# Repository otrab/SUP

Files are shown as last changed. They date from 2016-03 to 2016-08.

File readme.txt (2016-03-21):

Readme

Current on HDMI 5v line
http://forum.xda-developers.com/showthread.php?t=2384480

HDMI specification
https://en.wikipedia.org/wiki/HDMI
http://www.hdmi.org/installers/insidehdmicable.aspx

Great ideas
http://forum.arduino.cc/index.php?topic=119879.0
http://articulo.mercadolibre.cl/MLC-432821282-switch-hdmi-hasta-3-dispositivos-1080p-_JM ($4.800)
http://www.aliexpress.com/item/1pc-Switcher-Splitter-Cable-For-HDTV-3-IN-1-OUT-1080P-Hub-V1-4B-HDMI-Switch/32291909706.html

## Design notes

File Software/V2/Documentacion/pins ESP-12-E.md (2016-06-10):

# Pines ESP-12-E

Pin fisico | Puerto | Pin Arduino | Funciones internas
-----------|--------|-------------|-------------------
1          | RST    |             |
2          | ADC    | A0          | TOUT
3          | EN     |             |
4          | GPIO16 | 0           | WAKE
5          | GPIO14 | 5           | HSPICLK
6          | GPIO12 | 6           | HSPIQ
7          | GPIO13 | 7           | HSPID/CTS0/RXD2
8          | VDD    |             |
9          | GND    |             |
10         | GPIO15 | 8           | HSPICS/RTS0/TXD2
11         | GPIO2  | 4           | TXD1
12         | GPIO0  | 3           | SPICS2
13         | GPIO4  | 2           |
14         | GPIO5  | 1           |
15         | GPIO3  | 9           | RXD0
16         | GPIO1  | 10          | SPICS1/TXD0
17         | CS0    |             | SPI_INT/SD_D1
18         | MISO   |             | SPI_MISO/SD_D0
19         | GPIO9  |             | SD_D2
20         | GPIO10 |             | SPI_CS/SD_D3
21         | MOSI   |             | SPI_MOSI/SD_CMD
22         | SCLK   |             | SPI_CLK/SD_CLK

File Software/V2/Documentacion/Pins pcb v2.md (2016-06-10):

# Documentacion firmware V2
## Pines ATmega PCB V2

Pin TQFP | Puerto | Pin Arduino | Funciones internas | PCB            | Estados
---------|--------|-------------|--------------------|----------------|--------
1        | PD3    | 3           | PCINT19/OC2B/INT1  | EXP            | X
2        | PD4    | 4           | PCINT20/XCK/T0     | EXP            | X
9        | PD5    | 5           | PCINT21/OC0B/T1    | EXP            | X
10       | PD6    | 6           | PCINT22/OC0A/AIN0  | ESP_GPIO13_3V3 | 0 1 Z
11       | PD7    | 7           | PCINT23/AIN1       | RFID_OC_NRST   | 0 Z
12       | PB0    | 8           | PCINT0/CLKO/ICP1   | RFID_SS_3V3    | 0 1
13       | PB1    | 9           | PCINT1/OC1A        | LED            | 0 1
14       | PB2    | 10          | PCINT2/SS/OC1B     | EXP            | X
15       | PB3    | 11          | PCINT3/OC2A/MOSI   | RFID_MOSI_3V3  | 0 1
16       | PB4    | 12          | PCINT4/MISO        | RFID_MISO_3V3  | Z
17       | PB5    | 13          | SCK/PCINT5         | RFID_SCK_3V3   | 0 1
19       | ADC6   | -           |                    | EXP            |
22       | ADC7   | -           |                    | BOTON          | Z
23       | PC0    | A0          | ADC0/PCINT8        | BUZZER         | 0 1
24       | PC1    | A1          | ADC1/PCINT9        | RELE           | 0 1
25       | PC2    | A2          | ADC2/PCINT10       | HDMI_A_5V      | Z
26       | PC3    | A3          | ADC3/PCINT11       | HDMI_B_5V      | Z
27       | PC4    | A4          | ADC4/SDA/PCINT12   | SDA            | 0 1 Z
28       | PC5    | A5          | ADC5/SCL/PCINT13   | SCL            | 0 1 Z
29       | PC6    | RESET       | RESET/PCINT14      | RST_ATM_3V3    | Z
30       | PD0    | 0           | RXD/PCINT16        | ESP_TX_3V3     | Z
31       | PD1    | 1           | TXD/PCINT17        | ESP_RX_3V3     | 0 1
32       | PD2    | 2           | INT0/PCINT18       | EXP            | X

## Pines ESP PCB V2

Pin fisico | Puerto | Pin Arduino | Funciones internas | PCB            | Estados
-----------|--------|-------------|--------------------|----------------|--------
1          | RST    |             | RESET              | ESP_OC_NRST    |
2          | ADC    | A0          | TOUT               |                |
4          | GPIO16 | 16          | WAKE               |                | X
5          | GPIO14 | 14          | HSPICLK            | BOTON          | Z
6          | GPIO12 | 12          | HSPIQ              |                | X
7          | GPIO13 | 13          | HSPID/CTS0/RXD2    | ESP_GPIO13_3V3 | 0 1 Z
10         | GPIO15 | 15          | HSPICS/RTS0/TXD2   |                | Z
11         | GPIO2  | 2           | TXD1               |                | Z
12         | GPIO0  | 0           | SPICS2             | ESP_OC_NPROG   | Z
13         | GPIO4  | 4           |                    | RST_ATM_3V3    | 0 1
14         | GPIO5  | 5           |                    |                | X
15         | GPIO3  | 3           | RXD0               | ESP_RX_3V3     | Z
16         | GPIO1  | 1           | SPICS1/TXD0        | ESP_TX_3V3     | 0 1
17         | CS0    |             | SPI_INT/SD_D1      |                |
18         | MISO   |             | SPI_MISO/SD_D0     |                |
19         | GPIO9  |             | SD_D2              |                |
20         | GPIO10 |             | SPI_CS/SD_D3       |                |
21         | MOSI   |             | SPI_MOSI/SD_CMD    |                |
22         | SCLK   |             | SPI_CLK/SD_CLK     |                |

###Notas
Los estados permitidos de los pines se especifican para los pines configurables, ademas:
- Salida:
    - 0 = 0V
    - 1 = 3.3V 5V
- Entrada = Z (Alta impedancia)
- X = 0 1 Z (No importa pero deberian quedar en Z con pullup interno si no se usan)

El nodo ESP_GPIO13_3V3 conecta PD6 del ATmega con GPIO13 en el ESP, es importante que no queden ambos configurados como salida al mismo tiempo, siempre tiene que haber uno en Z.

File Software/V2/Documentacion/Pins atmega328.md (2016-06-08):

# Pines ATmega328 TQFP

Pin TQFP | Puerto | Pin Arduino | Funciones
---------|--------|-------------|-------------------
1        | PD3    | 3           | PCINT19/OC2B/INT1
2        | PD4    | 4           | PCINT20/XCK/T0
3        | GND    |             |
4        | VCC    |             |
5        | GND    |             |
6        | VCC    |             |
7        | PB6    | -           | PCINT6/XTAL1/TOSC1
8        | PB7    | -           | PCINT7/XTAL2/TOSC2
9        | PD5    | 5           | PCINT21/OC0B/T1
10       | PD6    | 6           | PCINT22/OC0A/AIN0
11       | PD7    | 7           | PCINT23/AIN1
12       | PB0    | 8           | PCINT0/CLKO/ICP1
13       | PB1    | 9           | PCINT1/OC1A
14       | PB2    | 10          | PCINT2/SS/OC1B
15       | PB3    | 11          | PCINT3/OC2A/MOSI
16       | PB4    | 12          | PCINT4/MISO
17       | PB5    | 13          | SCK/PCINT5
18       | AVCC   |             |
19       | ADC6   | -           |
20       | AREF   | AREF        |
21       | GND    |             |
22       | ADC7   | -           |
23       | PC0    | A0          | ADC0/PCINT8
24       | PC1    | A1          | ADC1/PCINT9
25       | PC2    | A2          | ADC2/PCINT10
26       | PC3    | A3          | ADC3/PCINT11
27       | PC4    | A4          | ADC4/SDA/PCINT12
28       | PC5    | A5          | ADC5/SCL/PCINT13
29       | PC6    | RESET       | RESET/PCINT14
30       | PD0    | 0           | RXD/PCINT16
31       | PD1    | 1           | TXD/PCINT17
32       | PD2    | 2           | INT0/PCINT18

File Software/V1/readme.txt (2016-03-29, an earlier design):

Opté por partir utilizando Arduíno para programar el ESP8266.

IDE preparado:

https://github.com/esp8266/Arduino/

	Install Arduino 1.6.8 from the Arduino website.
	Start Arduino and open Preferences window.
	Enter http://arduino.esp8266.com/stable/package_esp8266com_index.json into Additional Board Manager URLs field. You can add multiple URLs, separating them with commas.
	Open Boards Manager from Tools > Board menu and install esp8266 platform (and don't forget to select your ESP8266 board from Tools > Board menu after installation).

Referencias: 

https://github.com/esp8266/Arduino/blob/master/doc/reference.md

RTC wiki:

http://www.seeedstudio.com/wiki/index.php?title=Twig_-_RTC

https://git-scm.com/book/es/v1/Fundamentos-de-Git-Guardando-cambios-en-el-repositorio
Un firmware por cada componente para probarlos en el atmega.
Un firmware para el atmega que integra todos los componentes.
Un firmware para el esp8266 que incluye un servidor web local y envia la configuración por serial al atmega.

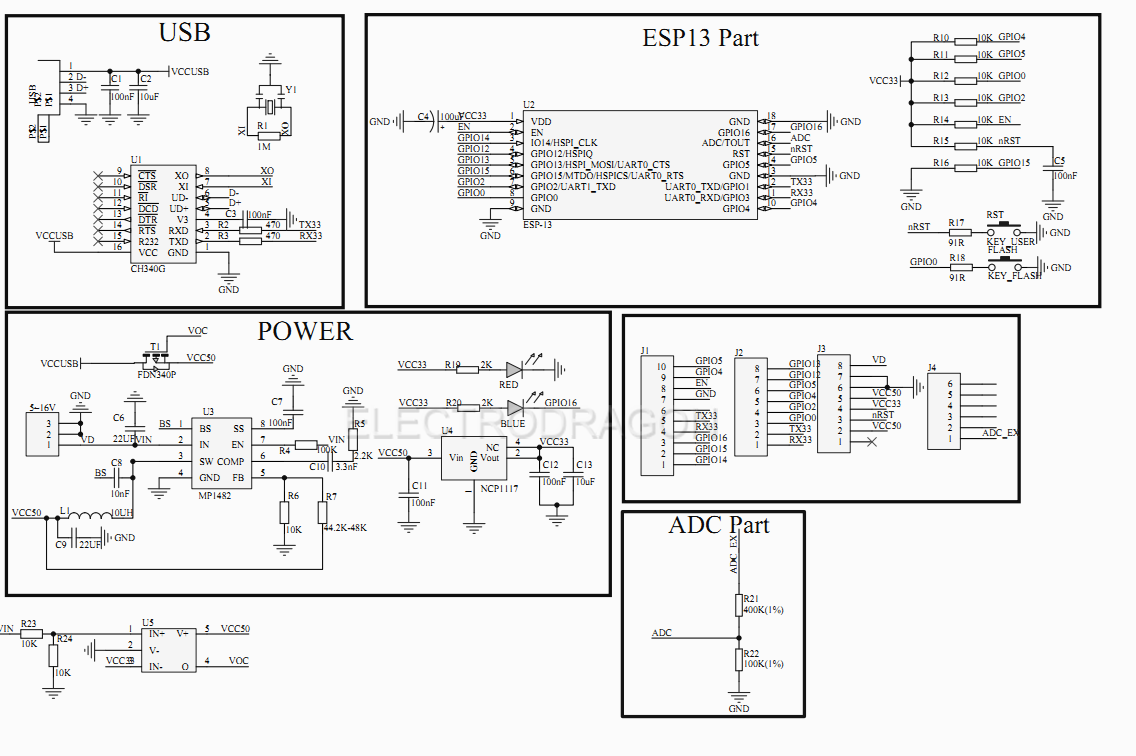
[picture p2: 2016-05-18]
Hardware/Material/ESP13-arduino_schematic.png

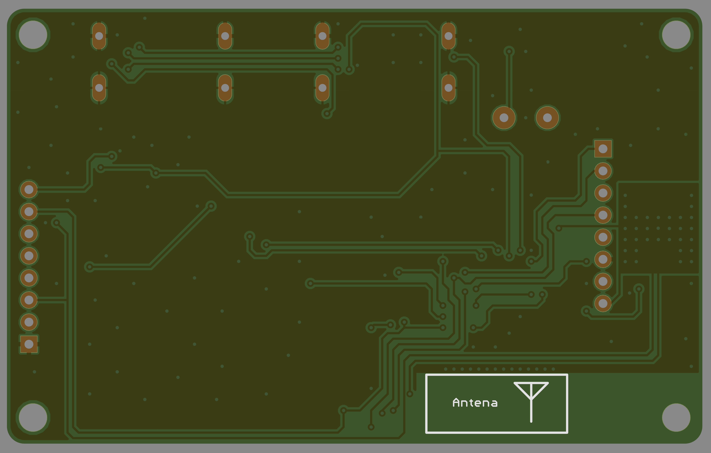
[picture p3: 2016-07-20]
Hardware/pcb v3/bottom.png

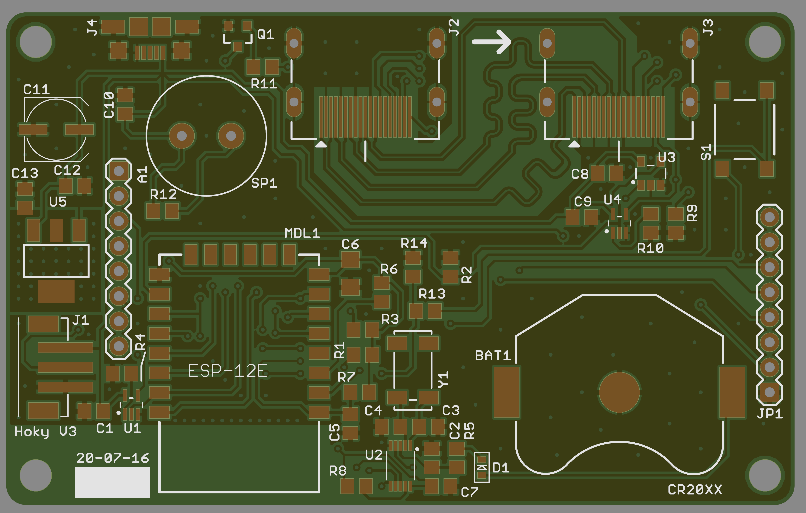
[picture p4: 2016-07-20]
Hardware/pcb v3/top.png

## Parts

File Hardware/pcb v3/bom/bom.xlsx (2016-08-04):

Qty | Value | Device | Package | Parts | Fabricante | Codigo fabricante | Codigo digikey | Description
1 | RFID-RC522 | RFID-RC522 | RFID-RC522 | A1
1 | BAT-HLD-001 | LINX-BAT-HLD-00120SMD | BATTCON_20MM | BAT1 | Linx Technologies Inc. | BAT-HLD-001 | BAT-HLD-001-ND | Battery Holders
6 | 100nF | C-USC0805 | C0805 | C1, C5, C7, C8, C9, C10 |  |  | 478-1395-1-ND | CAPACITOR, American symbol
1 | 100uF | CPOL-US | UD-6,3X5,8_NICHICON_LPADS | C11 |  |  | 565-2075-1-ND
2 | 10uF | C-USC0805 | C0805 | C12, C13 |  |  | 490-10516-1-ND | CAPACITOR, American symbol
1 | 100pF | C-USC0805 | C0805 | C2 |  |  | 399-1122-1-ND | CAPACITOR, American symbol
2 | 18pF | C-USC0805 | C0805 | C3, C4 |  |  | 709-1171-1-ND | CAPACITOR, American symbol
1 | 100uF | C-USC1206 | C1206 | C6 |  |  | 587-3395-1-ND | CAPACITOR, American symbol
1 | DB2S311 | DIODESOD-523 | SOD-523 | D1 | Panasonic Electronic Components | DB2S31100L | DB2S31100LCT-ND | Diode
1 | JST-3 | JST-3 | B3B-PH-SM4-TB | J1 | JST Sales America Inc. | B3B-PH-SM4-TB(LF)(SN) | 455-1735-1-ND
2 | HDMI | HDMI | 471511071 | J2, J3 | Molex, LLC | 471511071 | WM7083CT-ND
1 | 1981584-1 | 1981584-1 | 1981584-1 | J4 | TE Connectivity AMP Connectors | 1981584-1 | A97799CT-ND | Receptacle, micro-USB, type A/B
1 |  | M081X08 | 1X08 | JP1 |  |  | S1011EC-40-ND | Header 8
1 |  | ESP8266-12EESP8266-ESP12E | ESP8266-ESP12E | MDL1 |  |  |  | ESP8266-12E with additional I/O and GPIO04/05 corrected
1 | PMBT3904 | PMBT3904 | SOT-23-3 | Q1 |  |  | 568-1741-1-ND | PMBT3904
13 | 10k | R-US_R0805 | R0805 | R1, R2, R3, R4, R6, R7, R8, R9, R10, R13, R14, R15, R16 |  |  | RMCF0805JT10K0CT-ND | RESISTOR, American symbol
3 | 1k | R-US_R0805 | R0805 | R5, R11, R12 |  |  | RMCF0805JT1K00CT-ND | RESISTOR, American symbol
1 | PULSADOR-SPST-SMD-1-3-4 | PULSADOR-SPST-SMD-1-3-4 | PTS645SM43SMTR92 | S1 | C&K Components | PTS645SM43SMTR92 LFS | CKN9112CT-ND
1 | SPEAKER/PS12 | SPEAKER/PS12 | PS12 | SP1 | TDK Corporation | PS1240P02BT | 445-2525-1-ND
2 | 74HCT1G125GW | 74HCT1G125GW | SOT65P210X110-5N | U1, U4 | NXP Semiconductors | 74HCT1G125GW,125 | 568-4582-1-ND | Bus buffer/line driver
1 | MCP79510 | MCP79510 | MSOP10 | U2 | Microchip Technology | MCP79510-I/MS | MCP79510-I/MS-ND
1 | MC74VHC1GT66 | MC74VHC1GT66 | TSOP-5 | U3 | ON Semiconductor | M74VHC1GT66DTT1G | M74VHC1GT66DTT1GOSCT-ND
1 | NCP1117LPST33T3G | V_REG_LM1117SOT223 | SOT223 | U5 | ON Semiconductor | NCP1117LPST33T3G | NCP1117LPST33T3GOSCT-ND | Voltage Regulator LM1117
1 | CRYSTAL.ABS25 | CRYSTAL.ABS25 | ABS25 | Y1 | Abracon LLC | ABS25-32.768KHZ-T | 535-9166-2-ND
 | Precios digikey:
 | v3 x35 | $11.97 | 15x4
 | v2 x35 | $22.26
 |  | 46.22898216%
 | v3 x100 | $10.09
 | v2 x100 | $19.52
 |  | 48.28483607%
 | v3 x1000 | $7.13

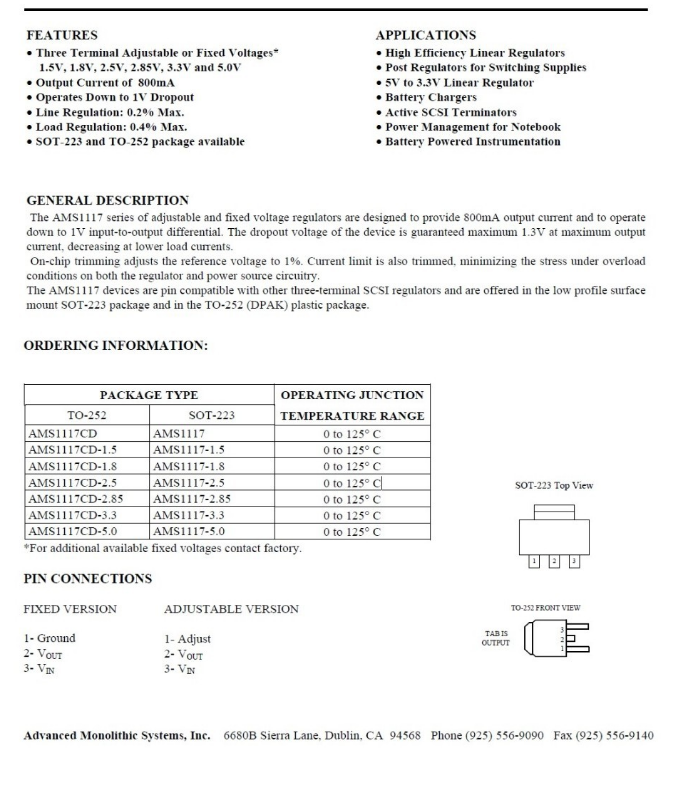
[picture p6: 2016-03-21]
Hardware/Material/ams1117.png

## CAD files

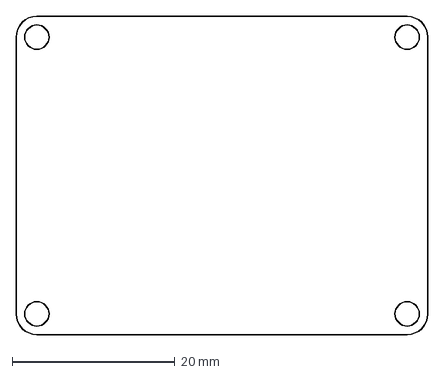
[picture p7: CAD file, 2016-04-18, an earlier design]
Hardware/pcb v1/cad/reles.dxf
50.6 x 39.1 mm

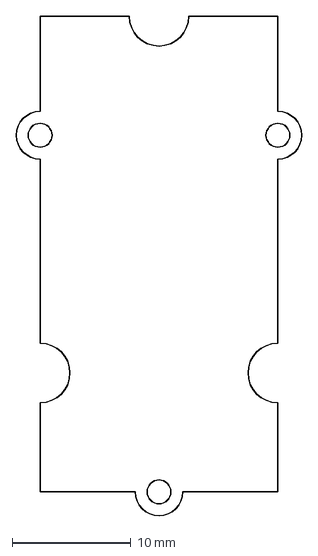
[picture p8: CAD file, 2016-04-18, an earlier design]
Hardware/pcb v1/cad/rfid y rtc.dxf
24.0 x 42.0 mm

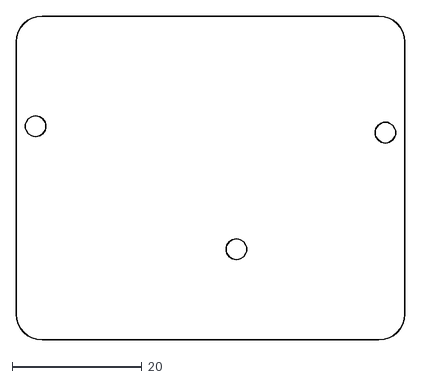
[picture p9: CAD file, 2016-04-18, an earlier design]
Hardware/pcb v1/cad/pcb v1 mod.dxf
60.0 x 50.0

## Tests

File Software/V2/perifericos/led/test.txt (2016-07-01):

/*
 * light_ws2812 example
 *
 * Created: 07.03.2014 12:49:30
 *  Author: Matthias Riegler
 */

#include "WS2812.h"

WS2812 LED(7); // 1 LED

cRGB value;

void setup() {
	LED.setOutput(9);     // Digital Pin 9
	value.b = 0;
	value.g = 0;
	value.r = 0;
	for(int i = 0; i < 7; i++) {
		LED.set_crgb_at(i, value);
	}
	LED.sync();
}
int k = 0;
bool f = 0;
void loop() {
	for(int i = 0; i < 7; i++) {
		if(i != 0) {
			value.SetHSV((k + (60 * (i-1))) % 360, 255, 30);
			LED.set_crgb_at(i, value);
		} else {
			value.SetHSV(0, 0, 0);
			LED.set_crgb_at(i, value);
		}
	}
	LED.sync();     // Sends the value to the LED
	delay(5);
	if(!f) {
		k=360;
	}
	if(f) {
		k--;
	}
	if(k == 360) {
		f = 1;
	}
	if(k == 0) {
		f = 0;
	}
}

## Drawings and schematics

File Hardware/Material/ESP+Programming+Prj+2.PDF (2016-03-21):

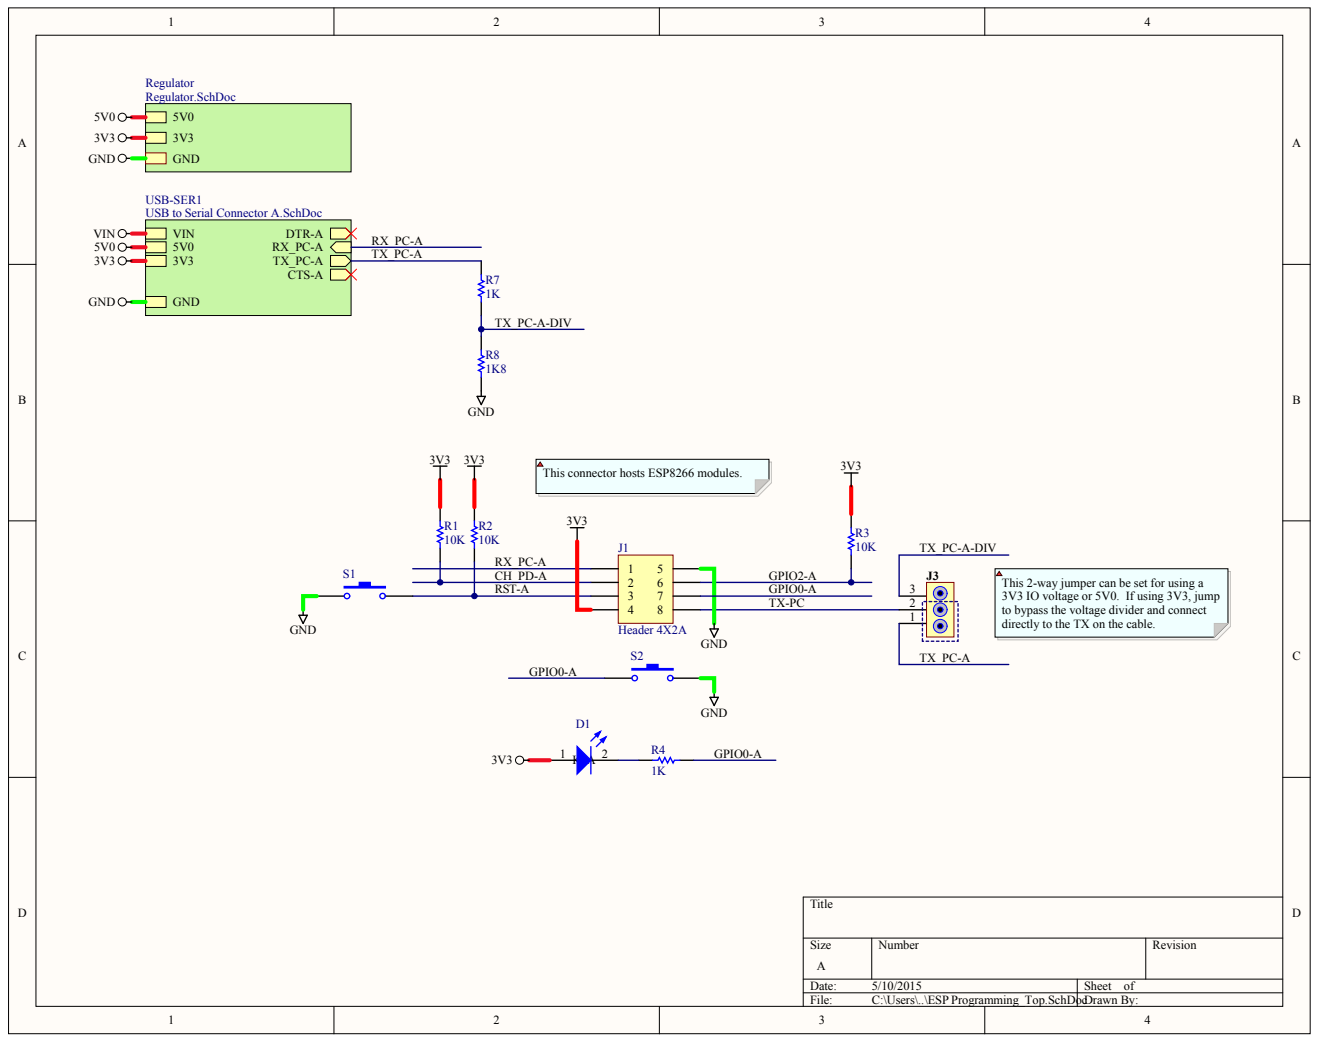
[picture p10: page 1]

This connector hosts ESP8266 modules.

This 2-way jumper can be set for using a
3V3 IO voltage or 5V0. If using 3V3, jump
to bypass the voltage divider and connect
directly to the TX on the cable.

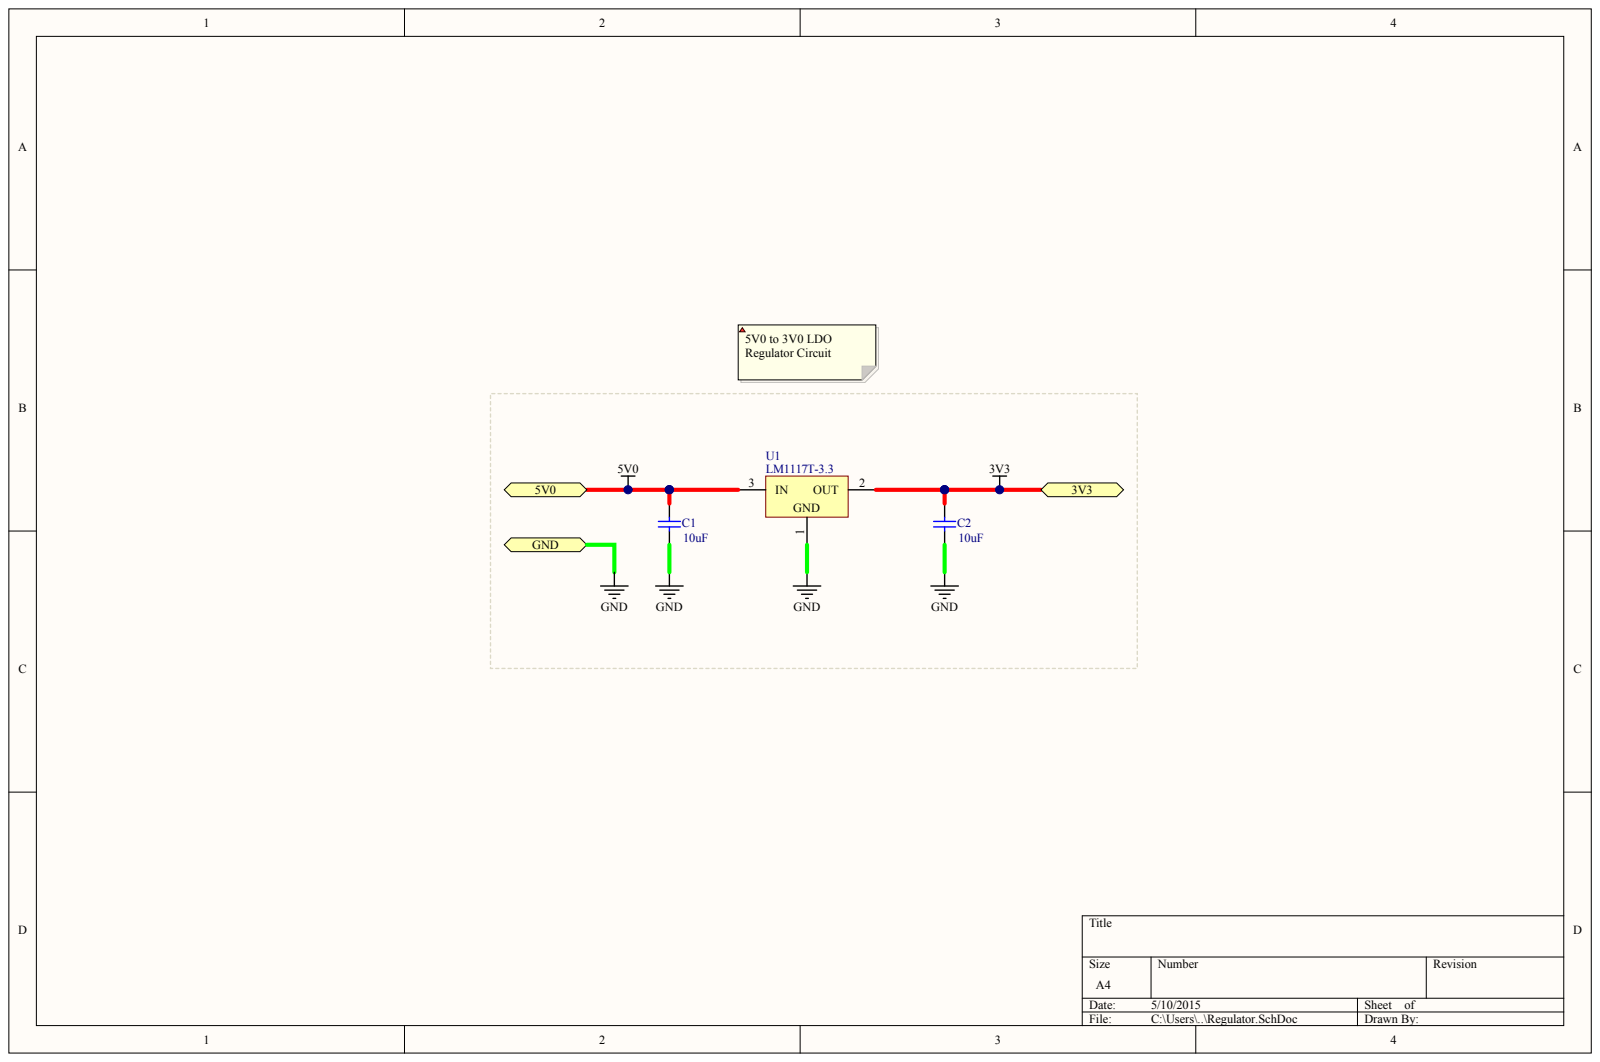
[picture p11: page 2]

Size A4 | Number | Revision

Date: 5/10/2015 | Sheet of
File: C:\Users\..\Regulator.SchDoc | Drawn By :

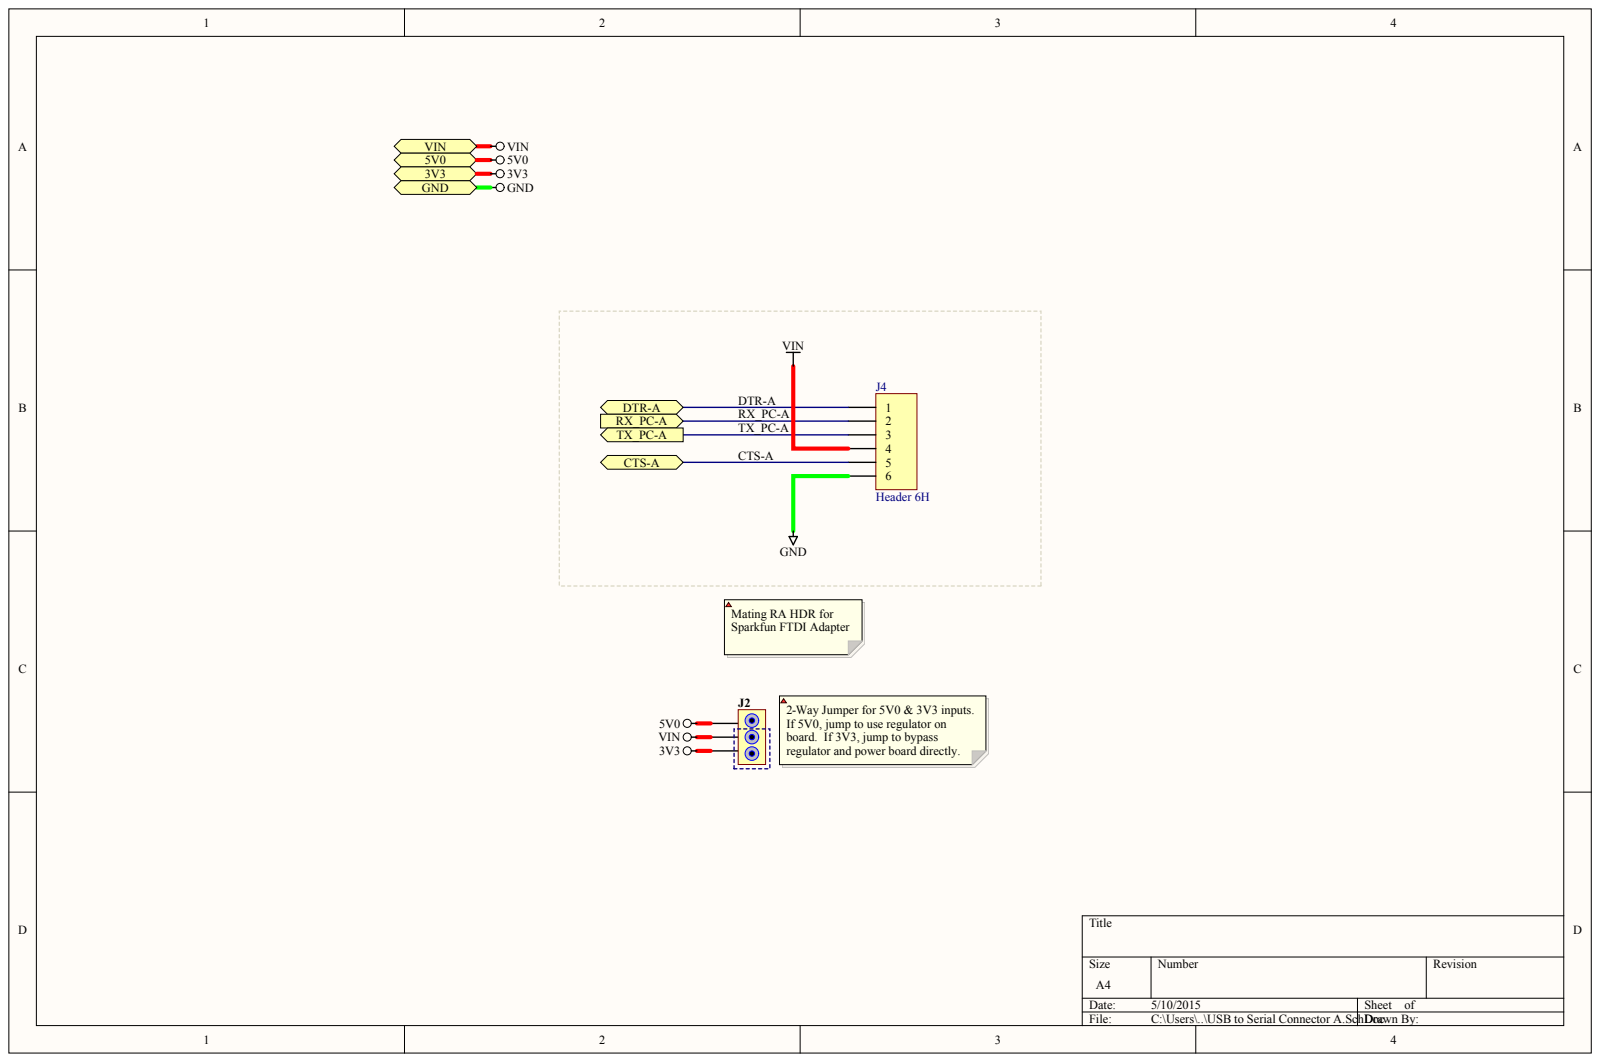
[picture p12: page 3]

Mating RA HDR for
Sparkfun FTDI Adapter

2-Way Jumper for 5V0 & 3V3 inputs.
If 5V0, jump to use regulator on
board. If 3V3, jump to bypass regulator and power board directly.

Size A4 | Number | Revision

Date: 5/10/2015 | Sheet of
File: C:\Users\..\USB to Serial Connector A.SchDocrawn By:

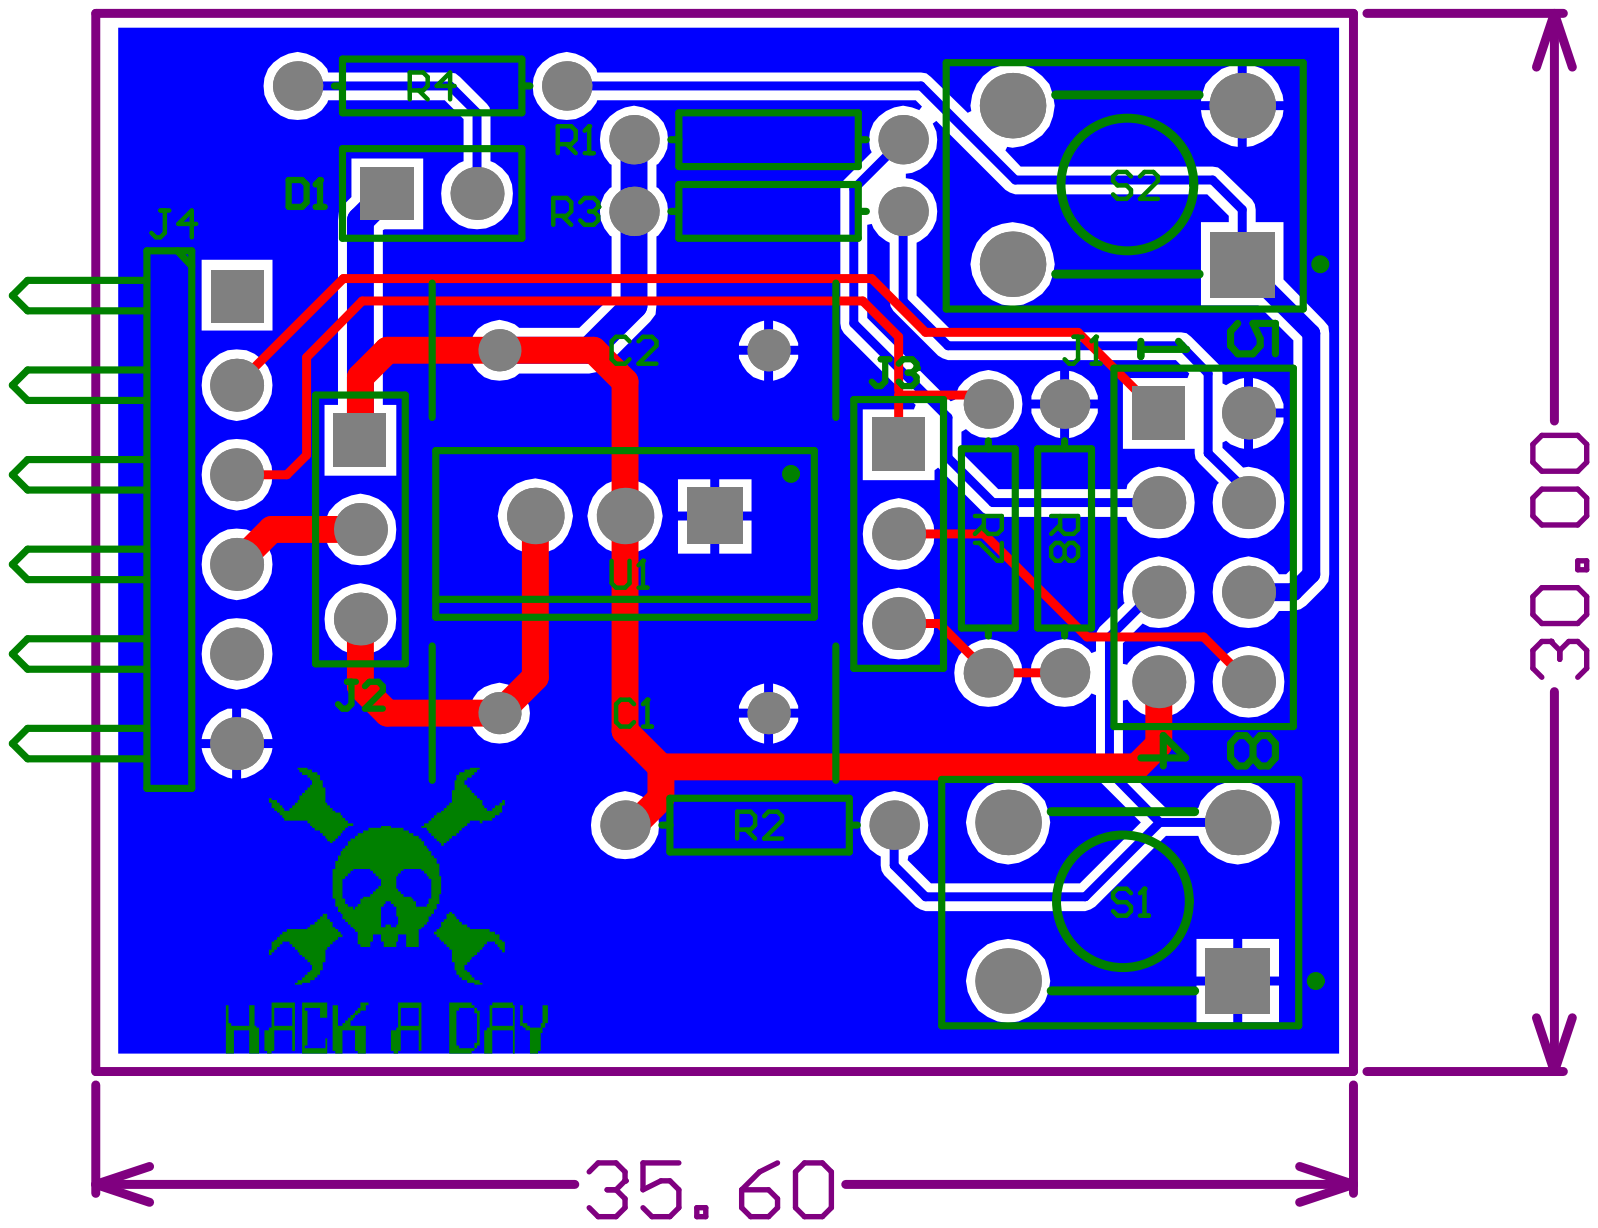
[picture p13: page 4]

Bill of Materials | <Parameter Title not found>
Source Data From: | ESP Programming Prj.PrjPcb
Project: | | ESP Programming Prj.PrjPcb
Variant: | | None
Creation Date: 5/10/2015 | 12:24:18 PM
Print Date: | 42134 | 42134.517
Footprint | Comment | LibRef | Designator | Description | Quantity
RAD-0.3 HDR1X2 HDR2X4_CE N HDR1X3 HDR1X6H AXIAL-0.3 NOPB-4 T03B | Cap LED2 Header 4X2A 3-WAY JUMPER Header 6H Res1 SW-PB LM1117T-3.3 | Cap LED2 Header 4X2A 3-WAY JUMPER Header 6H Res1 SW-PB CMP-0062-02490-2 | C1, C2 | Capacitor Typical RED, GREEN, YELLOW, AMBER GaAs LED Header, 4-Pin, Dual row 3-Way Jumper - Center Output Header, 6-Pin, Right Angle Resistor Switch 800mA Low-Dropout Linear Regulator, 3-pin TO-220 | 2
| | | D1 | | 1
| | | J1 | | 1
| | | J2, J3 | | 2
| | | J4 | | 1
| | | R1, R2, R3, R4, R7, R8 | | 6
| | | S1, S2 | | 2
| | | U1 | | 1
Approved Notes | | | | | 16

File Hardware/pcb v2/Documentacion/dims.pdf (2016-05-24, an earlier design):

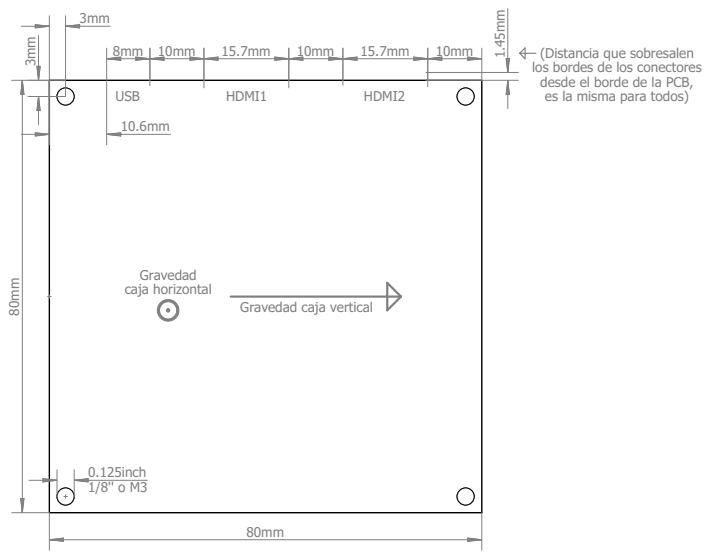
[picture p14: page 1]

(Distancia que sobresalen
los bordes de los conectores
desde el borde de la PCB, es la misma para todos)

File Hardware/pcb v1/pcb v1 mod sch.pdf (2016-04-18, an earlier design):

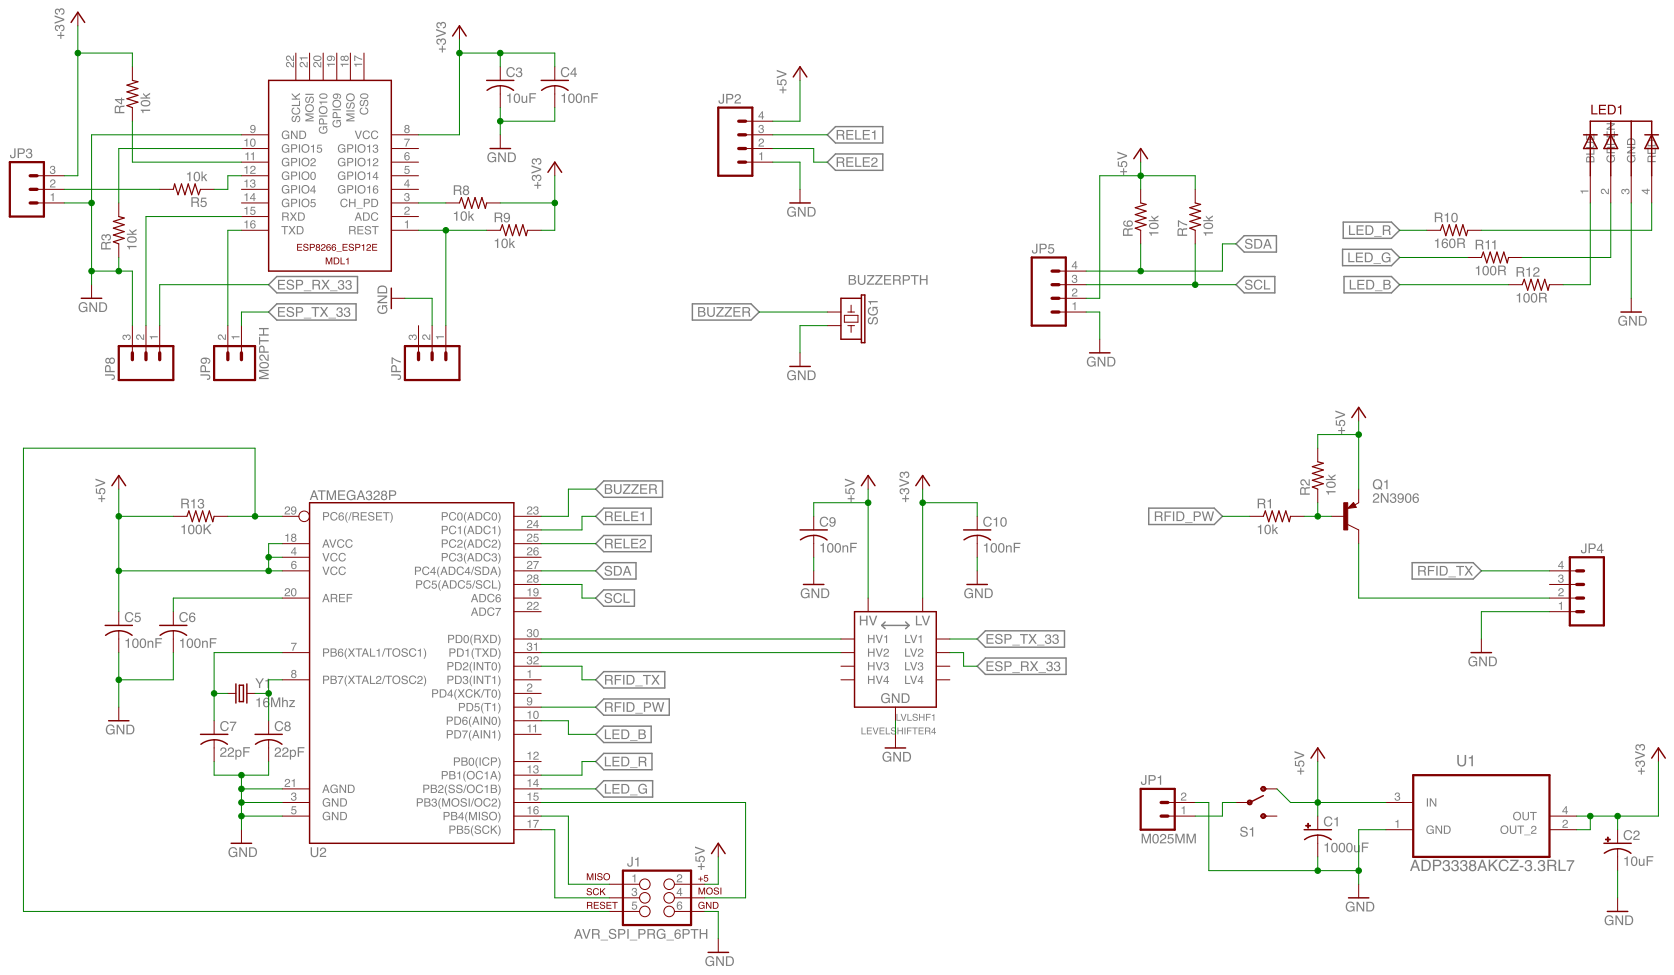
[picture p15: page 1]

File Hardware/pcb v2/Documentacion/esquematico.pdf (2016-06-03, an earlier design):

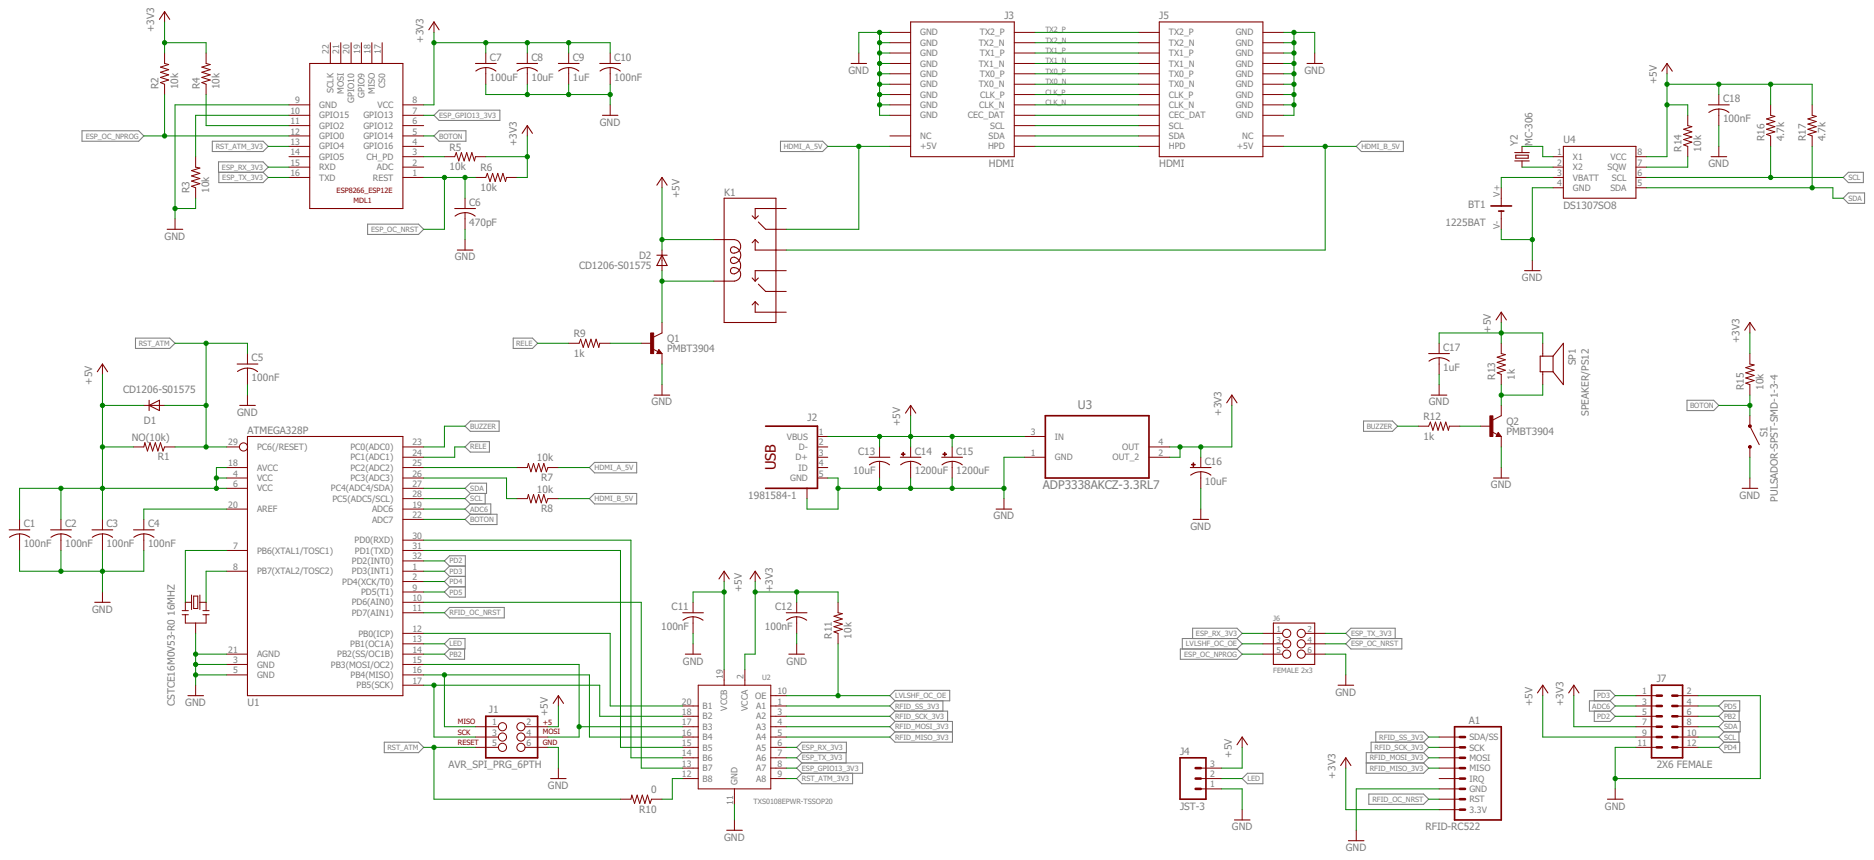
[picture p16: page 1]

C4 | 22 ADC6 ADC6 BOTON

SDA/SS
IRQ MISO MOSI SCK

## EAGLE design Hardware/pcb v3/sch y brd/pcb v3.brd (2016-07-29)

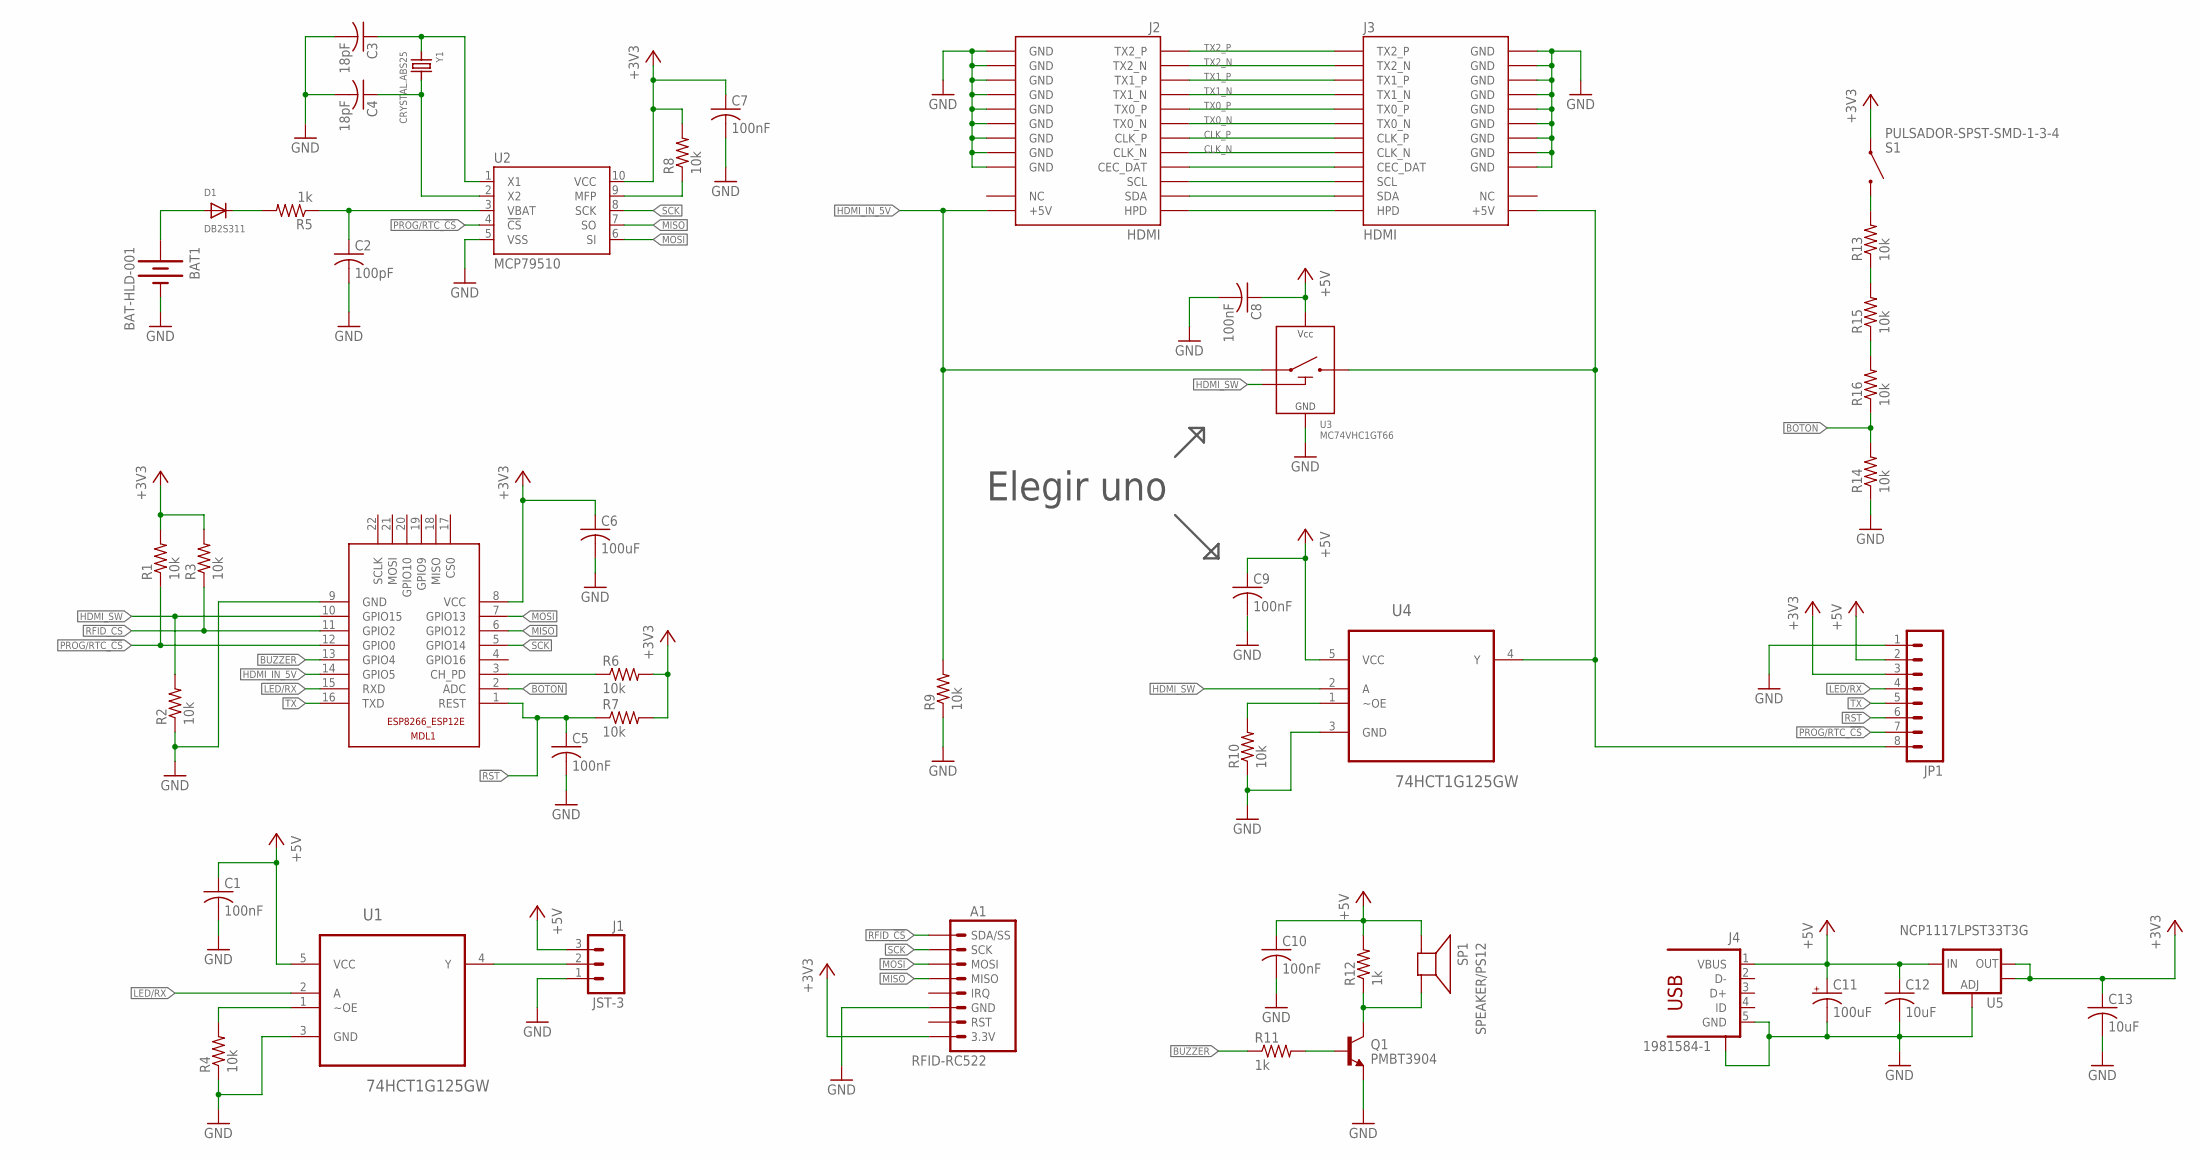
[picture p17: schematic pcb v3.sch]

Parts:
A1: RFID-RC522
BAT1: BAT-HLD-001; BATTCON_20MM
C1, C5, C7, C8, C9, C10: 100nF; C0805
C2: 100pF; C0805
C3, C4: 18pF; C0805
C6: 100uF; C1206
C11: 100uF; UD-6,3X5,8_NICHICON_LPADS
C12, C13: 10uF; C0805
D1: DB2S311; SOD-523
J1: JST-3; B3B-PH-SM4-TB
J2, J3: HDMI; 0471511071
J4: 1981584-1
JP1: M081X08; 1X08
MDL1: ESP8266-12EESP8266-ESP12E; ESP8266-ESP12E
Q1: PMBT3904; SOT-23-3
R1, R2, R3, R4, R6, R7, R8, R9, R10, R13, R14, R15, R16: 10k; R0805
R5, R11, R12: 1k; R0805
S1: PULSADOR-SPST-SMD-1-3-4; PTS645SM43SMTR92
SP1: SPEAKER/PS12; PS12
U1, U4: 74HCT1G125GW; SOT65P210X110-5N
U2: MCP79510; MSOP10
U3: MC74VHC1GT66; TSOP-5
U5: NCP1117LPST33T3G; SOT223
Y1: CRYSTAL.ABS25; ABS25

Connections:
!RST: C5.1, JP1.6, MDL1.1 (REST), R7.1
+3V3: A1.3.3V, C6.1, C7.1, C13.1, JP1.3, MDL1.8 (VCC), R1.2, R3.2, R6.2, R7.2, R8.2, S1.P$1, U2.10 (VCC), U5.2 (OUT), U5.4 (OUT)
+5V: C1.1, C8.1, C9.1, C10.1, C11.+, C12.1, J1.3, J4.1 (VBUS), JP1.2, R12.2, SP1.P$1 (+), U1.5 (VCC), U3.5, U4.5 (VCC), U5.3 (IN)
BOTON: MDL1.2 (ADC), R14.2, R16.1
BUZZER: MDL1.13 (GPIO4), R11.1
CLK_N: J2.P$12 (CLK_N), J3.P$12 (CLK_N)
CLK_P: J2.P$10 (CLK_P), J3.P$10 (CLK_P)
GND: A1.GND, BAT1.2 (-), C1.2, C2.2, C3.2, C4.2, C5.2, C6.2, C7.2, C8.2, C9.2, C10.2, C11.-, C12.2, C13.2, J1.1, J2.P$2 (GND), J2.P$5 (GND), J2.P$8 (GND), J2.P$11 (GND), J2.P$17 (GND), J2.P$20 (GND), J2.P$21 (GND), J2.P$22 (GND), J2.P$23 (GND), J3.P$2 (GND), J3.P$5 (GND), J3.P$8 (GND), J3.P$11 (GND), J3.P$17 (GND), J3.P$20 (GND), J3.P$21 (GND), J3.P$22 (GND), J3.P$23 (GND), J4.5 (GND), J4.S1, J4.S2, J4.S3, J4.S4, JP1.1, MDL1.9 (GND), Q1.2 (E), R2.1, R4.1, R9.1, R10.1, R14.1, U1.3 (GND), U2.5 (VSS), U3.3, U4.3 (GND), U5.1 (ADJ)
HDMI_IN_5V: J2.P$18 (+5V), MDL1.14 (GPIO5), R9.2, U3.1
HDMI_OUT_5V: J3.P$18 (+5V), JP1.8, U3.2, U4.4 (Y)
HDMI_SW: MDL1.10 (GPIO15), R2.2, U3.4, U4.2 (A)
LED/RX: JP1.4, MDL1.15 (RXD), U1.2 (A)
MISO: A1.MISO, MDL1.6 (GPIO12), U2.7 (SO)
MOSI: A1.MOSI, MDL1.7 (GPIO13), U2.6 (SI)
unnamed: Q1.1 (B), R11.2
unnamed: C3.1, U2.1 (X1), Y1.1
unnamed: C4.1, U2.2 (X2), Y1.4 (2)
unnamed: R4.2, U1.1 (~OE)
unnamed: Q1.3 (C), R12.1, SP1.P$2 (-)
unnamed: R8.1, U2.9 (MFP)
unnamed: BAT1.1 (+), D1.A
unnamed: D1.K (C), R5.2
unnamed: C2.1, R5.1, U2.3 (VBAT)
unnamed: MDL1.3 (CH_PD), R6.1
unnamed: J1.2, U1.4 (Y)
unnamed: R13.2, S1.P$3, S1.P$4
unnamed: R13.1, R15.2
unnamed: R15.1, R16.2
unnamed: R10.2, U4.1 (~OE)
unnamed: J2.P$13 (CEC_DAT), J3.P$13 (CEC_DAT)
unnamed: J2.P$15 (SCL), J3.P$15 (SCL)
unnamed: J2.P$16 (SDA), J3.P$16 (SDA)
unnamed: J2.P$19 (HPD), J3.P$19 (HPD)
PROG/RTC_!CS: JP1.7, MDL1.12 (GPIO0), R1.1, U2.4 (!CS)
RFID_!CS: A1.SDA (SDA/SS), MDL1.11 (GPIO2), R3.1
SCK: A1.SCK, MDL1.5 (GPIO14), U2.8 (SCK)
TX: JP1.5, MDL1.16 (TXD)
TX0_N: J2.P$9 (TX0_N), J3.P$9 (TX0_N)
TX0_P: J2.P$7 (TX0_P), J3.P$7 (TX0_P)
TX1_N: J2.P$6 (TX1_N), J3.P$6 (TX1_N)
TX1_P: J2.P$4 (TX1_P), J3.P$4 (TX1_P)
TX2_N: J2.P$3 (TX2_N), J3.P$3 (TX2_N)
TX2_P: J2.P$1 (TX2_P), J3.P$1 (TX2_P)

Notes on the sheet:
Elegir uno

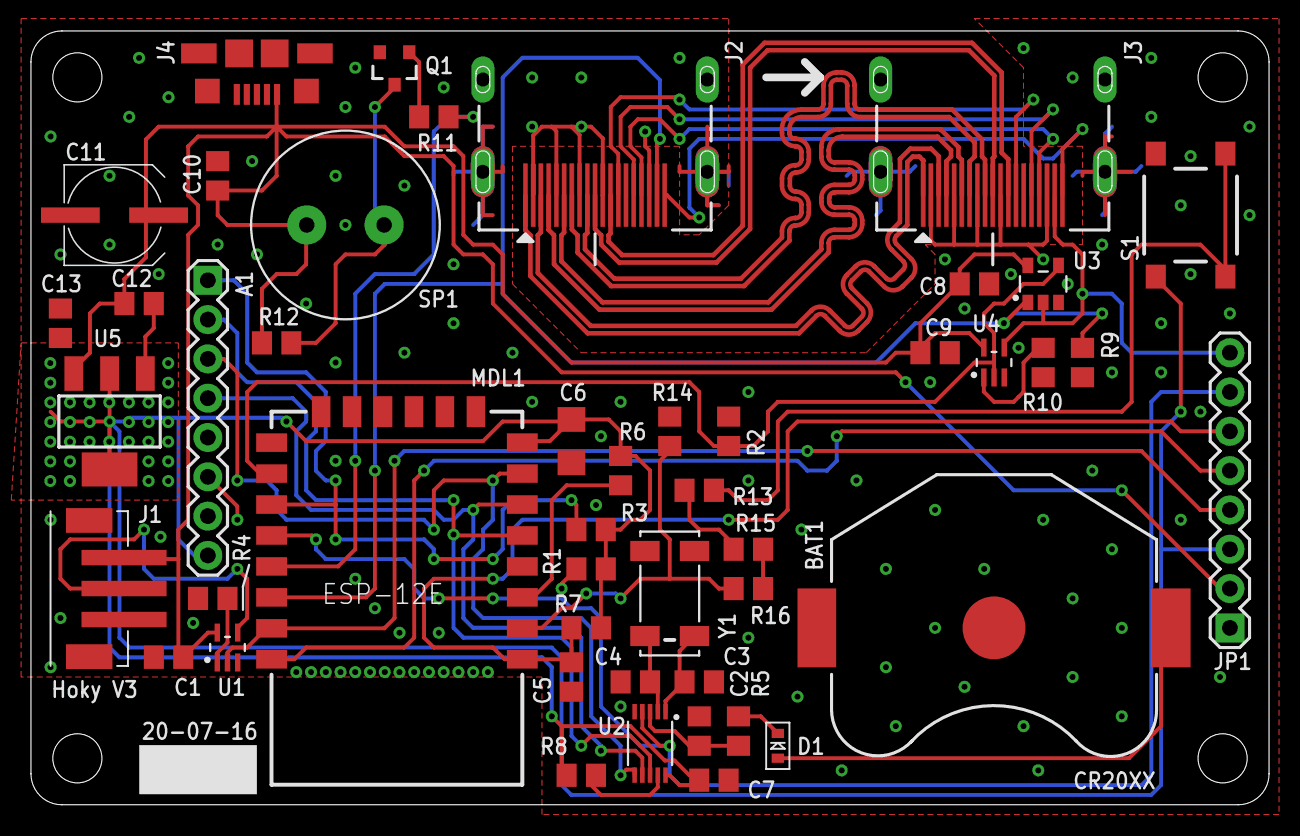
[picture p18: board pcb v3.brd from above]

Board: 2 copper layers, 80.0 x 50.0 mm, 47 parts (0 on the bottom side), 43 nets.

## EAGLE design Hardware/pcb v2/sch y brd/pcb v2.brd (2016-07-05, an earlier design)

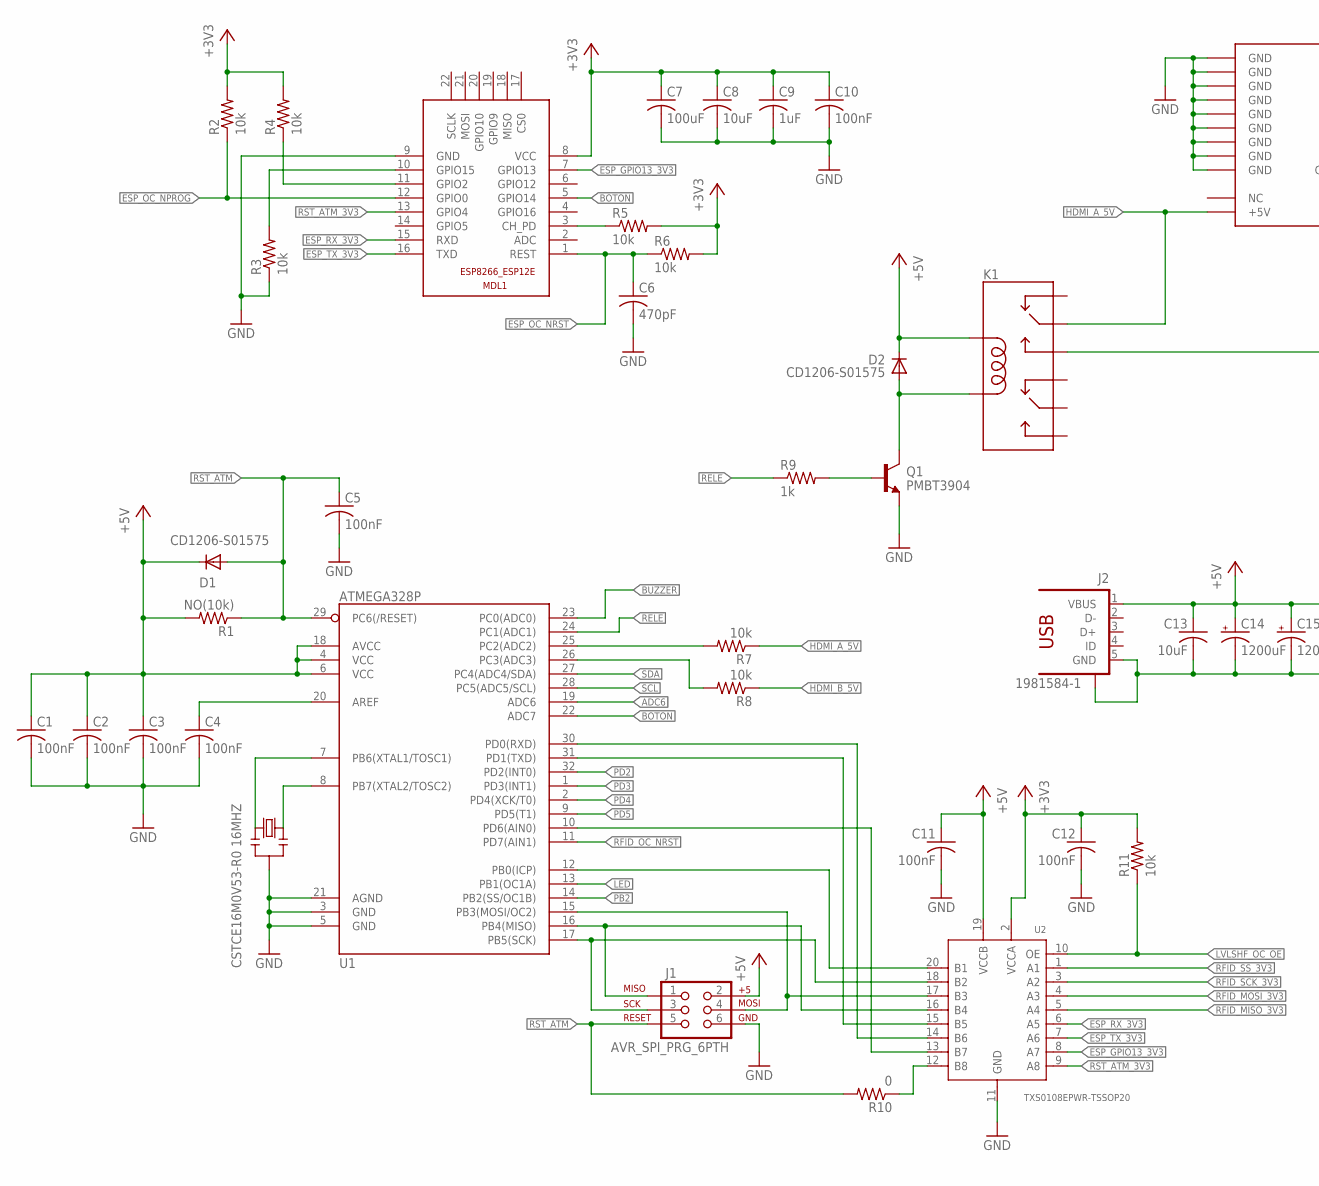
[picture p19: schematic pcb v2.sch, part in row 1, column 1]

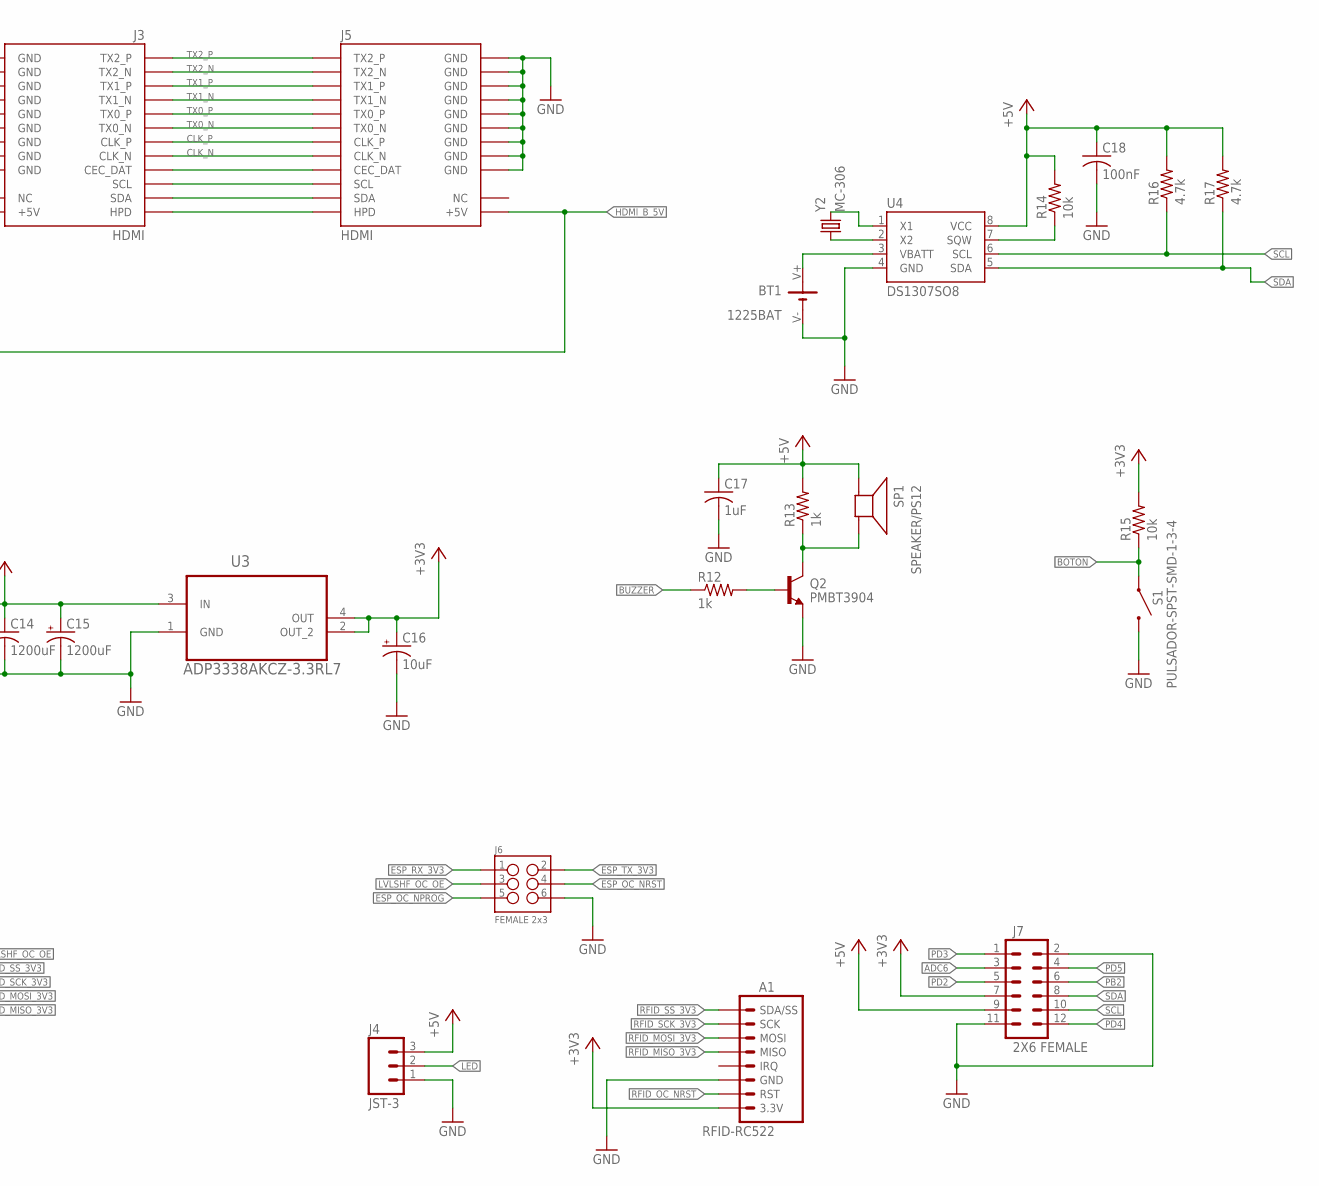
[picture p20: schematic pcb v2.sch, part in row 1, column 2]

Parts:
A1: RFID-RC522
BT1: 1225BAT; BHSD-1225-SM
C1, C2, C3, C4, C5, C10, C11, C12, C18: 100nF; C0603
C6: 470pF; C0603
C7: 100uF; C1206
C8, C13: 10uF; C0805
C9, C17: 1uF; C0805
C14, C15: 1200uF; UD-10X10_NICHICON
C16: 10uF; UD-5X5,8_NICHICON
D1, D2: CD1206-S01575; MINIMELF
J1: AVR_SPI_PRG_6PTH; 2X3
J2: 1981584-1
J3, J5: HDMI; 0471511071
J4: JST-3; B3B-PH-SM4-TB
J6: FEMALE 2x3; 2X3
J7: 2X6 FEMALE; 2X6
K1: RELAY_EE2; RELAY-EE2
MDL1: ESP8266-12EESP8266-ESP12E; ESP8266-ESP12E
Q1, Q2: PMBT3904; SOT-23-3
R1: NO(10k); R0805
R2, R3, R4, R5, R6, R7, R8, R11, R14, R15: 10k; R0603
R9, R12, R13: 1k; R0805
R10: 0; R0805
R16, R17: 4.7k; R0603
S1: PULSADOR-SPST-SMD-1-3-4; PTS645SM43SMTR92
SP1: SPEAKER/PS12; PS12
U1: ATMEGA328P; TQFP32-08
U2: TXS0108EPWR-TSSOP20; TSSOP20-0.65-6.5X4.4MM
U3: ADP3338AKCZ-3.3RL7; SOT230P700X180-4N
U4: DS1307SO8; SO08
Y1: CSTCE16M0V53-R0 16MHZ; RESONATOR
Y2: MC-306

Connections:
+3V3: A1.3.3V, C7.1, C8.1, C9.1, C10.1, C12.1, C16.+, J7.7, MDL1.8 (VCC), R2.2, R4.2, R5.2, R6.2, R11.2, R15.2, U2.2 (VCCA), U3.2 (OUT_2), U3.4 (OUT)
+5V: C1.1, C2.1, C3.1, C11.1, C13.1, C14.+, C15.+, C17.1, C18.1, D1.C, D2.C, J1.2, J2.1 (VBUS), J4.3, J7.9, K1.1 (COIL+), R1.2, R13.2, R14.2, R16.2, R17.2, SP1.P$1 (+), U1.4 (VCC), U1.6 (VCC), U1.18 (AVCC), U2.19 (VCCB), U3.3 (IN), U4.8 (VCC)
ADC6: J7.3, U1.19 (ADC6)
BOTON: MDL1.5 (GPIO14), R15.1, S1.P$1, U1.22 (ADC7)
BUZZER: R12.1, U1.23 (PC0(ADC0))
CLK_N: J3.P$12 (CLK_N), J5.P$12 (CLK_N)
CLK_P: J3.P$10 (CLK_P), J5.P$10 (CLK_P)
ESP_GPIO13_3V3: MDL1.7 (GPIO13), U2.8 (A7)
ESP_OC_NPROG: J6.5, MDL1.12 (GPIO0), R2.1
ESP_OC_NRST: C6.1, J6.4, MDL1.1 (REST), R6.1
ESP_RX_3V3: J6.1, MDL1.15 (RXD), U2.6 (A5)
ESP_TX_3V3: J6.2, MDL1.16 (TXD), U2.7 (A6)
GND: A1.GND, BT1.V-, C1.2, C2.2, C3.2, C4.2, C5.2, C6.2, C7.2, C8.2, C9.2, C10.2, C11.2, C12.2, C13.2, C14.-, C15.-, C16.-, C17.2, C18.2, J1.6, J2.5 (GND), J2.S1, J2.S2, J2.S3, J2.S4, J3.P$2 (GND), J3.P$5 (GND), J3.P$8 (GND), J3.P$11 (GND), J3.P$17 (GND), J3.P$20 (GND), J3.P$21 (GND), J3.P$22 (GND), J3.P$23 (GND), J4.1, J5.P$2 (GND), J5.P$5 (GND), J5.P$8 (GND), J5.P$11 (GND), J5.P$17 (GND), J5.P$20 (GND), J5.P$21 (GND), J5.P$22 (GND), J5.P$23 (GND), J6.6, J7.2, J7.11, MDL1.9 (GND), Q1.2 (E), Q2.2 (E), R3.1, S1.P$3, S1.P$4, U1.3 (GND), U1.5 (GND), U1.21 (AGND), U2.11 (GND), U3.1 (GND), U4.4 (GND), Y1.2
HDMI_A_5V: J3.P$18 (+5V), K1.4 (MAIN1), R7.1
HDMI_B_5V: J5.P$18 (+5V), K1.5 (OFF1), R8.1
LED: J4.2, U1.13 (PB1(OC1A))
LVLSHF_OC_OE: J6.3, R11.1, U2.10 (OE)
unnamed: Q2.1 (B), R12.2
unnamed: U4.1 (X1), Y2.4 (2)
unnamed: U4.2 (X2), Y2.1
unnamed: U1.8 (PB7(XTAL2/TOSC2)), Y1.3
unnamed: Q2.3 (C), R13.1, SP1.P$2 (-)
unnamed: R14.1, U4.7 (SQW)
unnamed: R10.1, U2.12 (B8)
unnamed: U1.12 (PB0(ICP)), U2.20 (B1)
unnamed: BT1.V+, U4.3 (VBATT)
unnamed: MDL1.3 (CH_PD), R5.1
unnamed: U1.7 (PB6(XTAL1/TOSC1)), Y1.1
unnamed: MDL1.11 (GPIO2), R4.1
unnamed: C4.1, U1.20 (AREF)
unnamed: D2.A, K1.12 (COIL-), Q1.3 (C)
unnamed: MDL1.10 (GPIO15), R3.2
unnamed: J1.3, U1.17 (PB5(SCK)), U2.18 (B2)
unnamed: J1.1, U1.16 (PB4(MISO)), U2.16 (B4)
unnamed: J1.4, U1.15 (PB3(MOSI/OC2)), U2.17 (B3)
unnamed: Q1.1 (B), R9.2
unnamed: U1.30 (PD0(RXD)), U2.14 (B6)
unnamed: U1.31 (PD1(TXD)), U2.15 (B5)
unnamed: J3.P$13 (CEC_DAT), J5.P$13 (CEC_DAT)
unnamed: J3.P$15 (SCL), J5.P$15 (SCL)
unnamed: J3.P$16 (SDA), J5.P$16 (SDA)
unnamed: J3.P$19 (HPD), J5.P$19 (HPD)
unnamed: R7.2, U1.25 (PC2(ADC2))
unnamed: R8.2, U1.26 (PC3(ADC3))
unnamed: U1.10 (PD6(AIN0)), U2.13 (B7)
PB2: J7.6, U1.14 (PB2(SS/OC1B))
PD2: J7.5, U1.32 (PD2(INT0))
PD3: J7.1, U1.1 (PD3(INT1))
PD4: J7.12, U1.2 (PD4(XCK/T0))
PD5: J7.4, U1.9 (PD5(T1))
RELE: R9.1, U1.24 (PC1(ADC1))
RFID_MISO_3V3: A1.MISO, U2.5 (A4)
RFID_MOSI_3V3: A1.MOSI, U2.4 (A3)
RFID_OC_NRST: A1.RST, U1.11 (PD7(AIN1))
RFID_SCK_3V3: A1.SCK, U2.3 (A2)
RFID_SS_3V3: A1.SDA (SDA/SS), U2.1 (A1)
RST_ATM: C5.1, D1.A, J1.5, R1.1, R10.2, U1.29 (PC6(/RESET))
RST_ATM_3V3: MDL1.13 (GPIO4), U2.9 (A8)
SCL: J7.10, R16.1, U1.28 (PC5(ADC5/SCL)), U4.6 (SCL)
SDA: J7.8, R17.1, U1.27 (PC4(ADC4/SDA)), U4.5 (SDA)
TX0_N: J3.P$9 (TX0_N), J5.P$9 (TX0_N)
TX0_P: J3.P$7 (TX0_P), J5.P$7 (TX0_P)
TX1_N: J3.P$6 (TX1_N), J5.P$6 (TX1_N)
TX1_P: J3.P$4 (TX1_P), J5.P$4 (TX1_P)
TX2_N: J3.P$3 (TX2_N), J5.P$3 (TX2_N)
TX2_P: J3.P$1 (TX2_P), J5.P$1 (TX2_P)

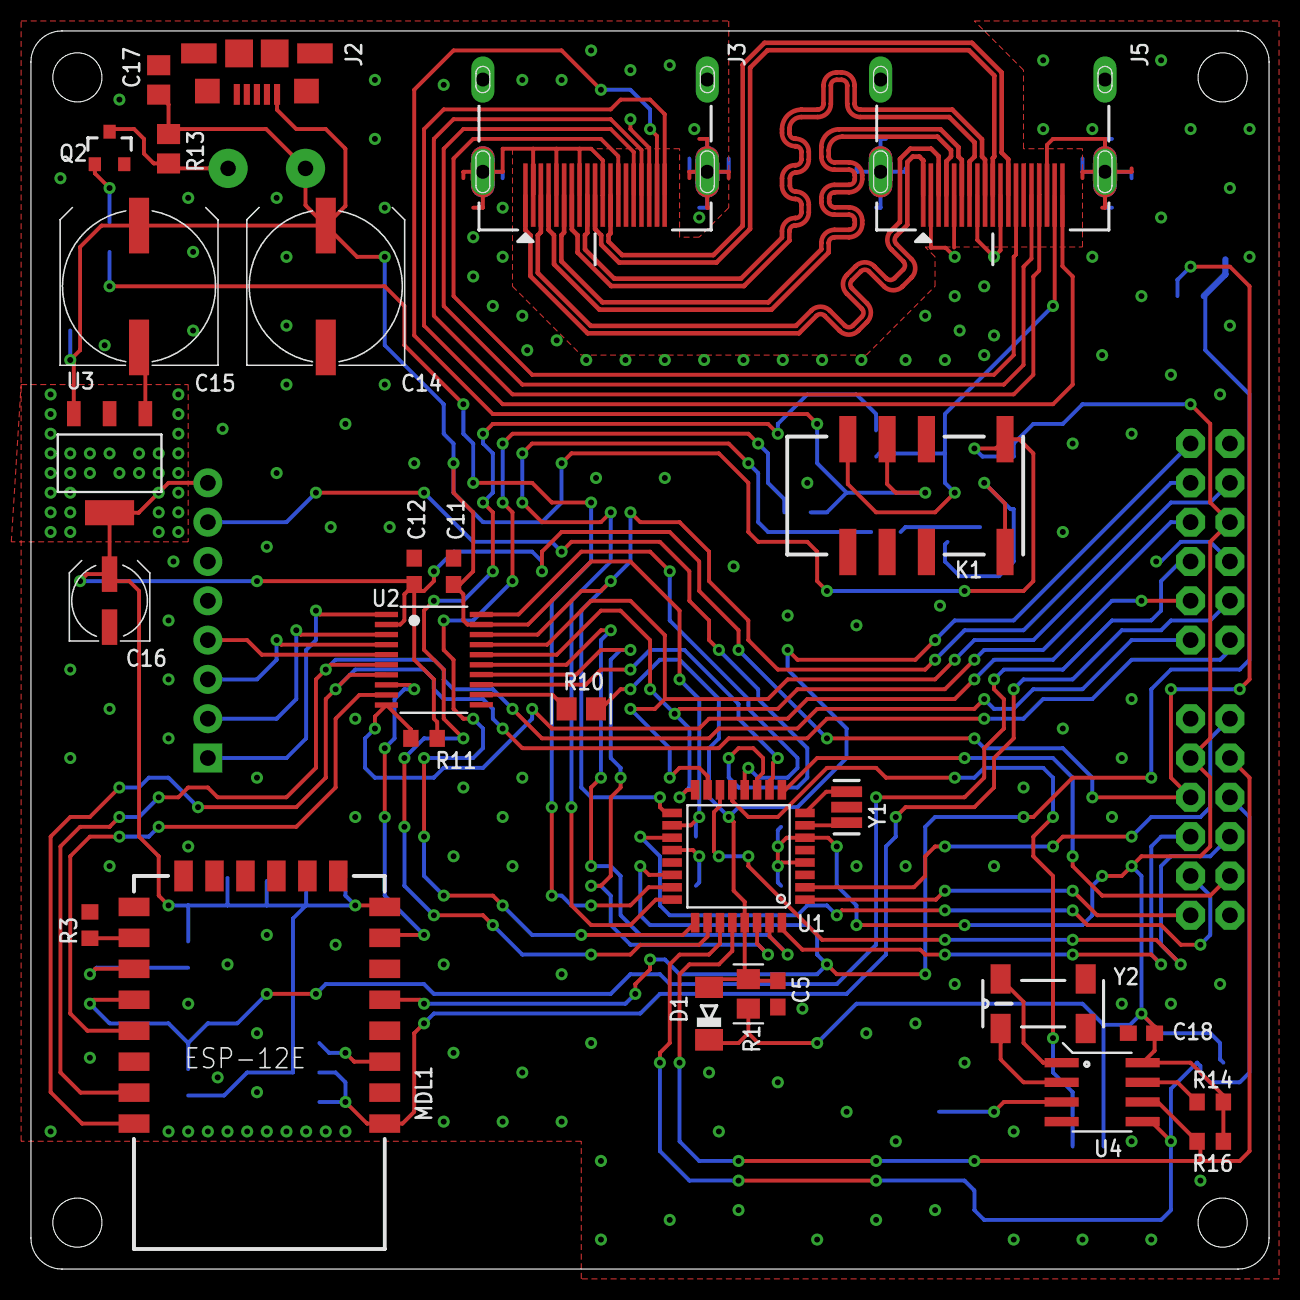
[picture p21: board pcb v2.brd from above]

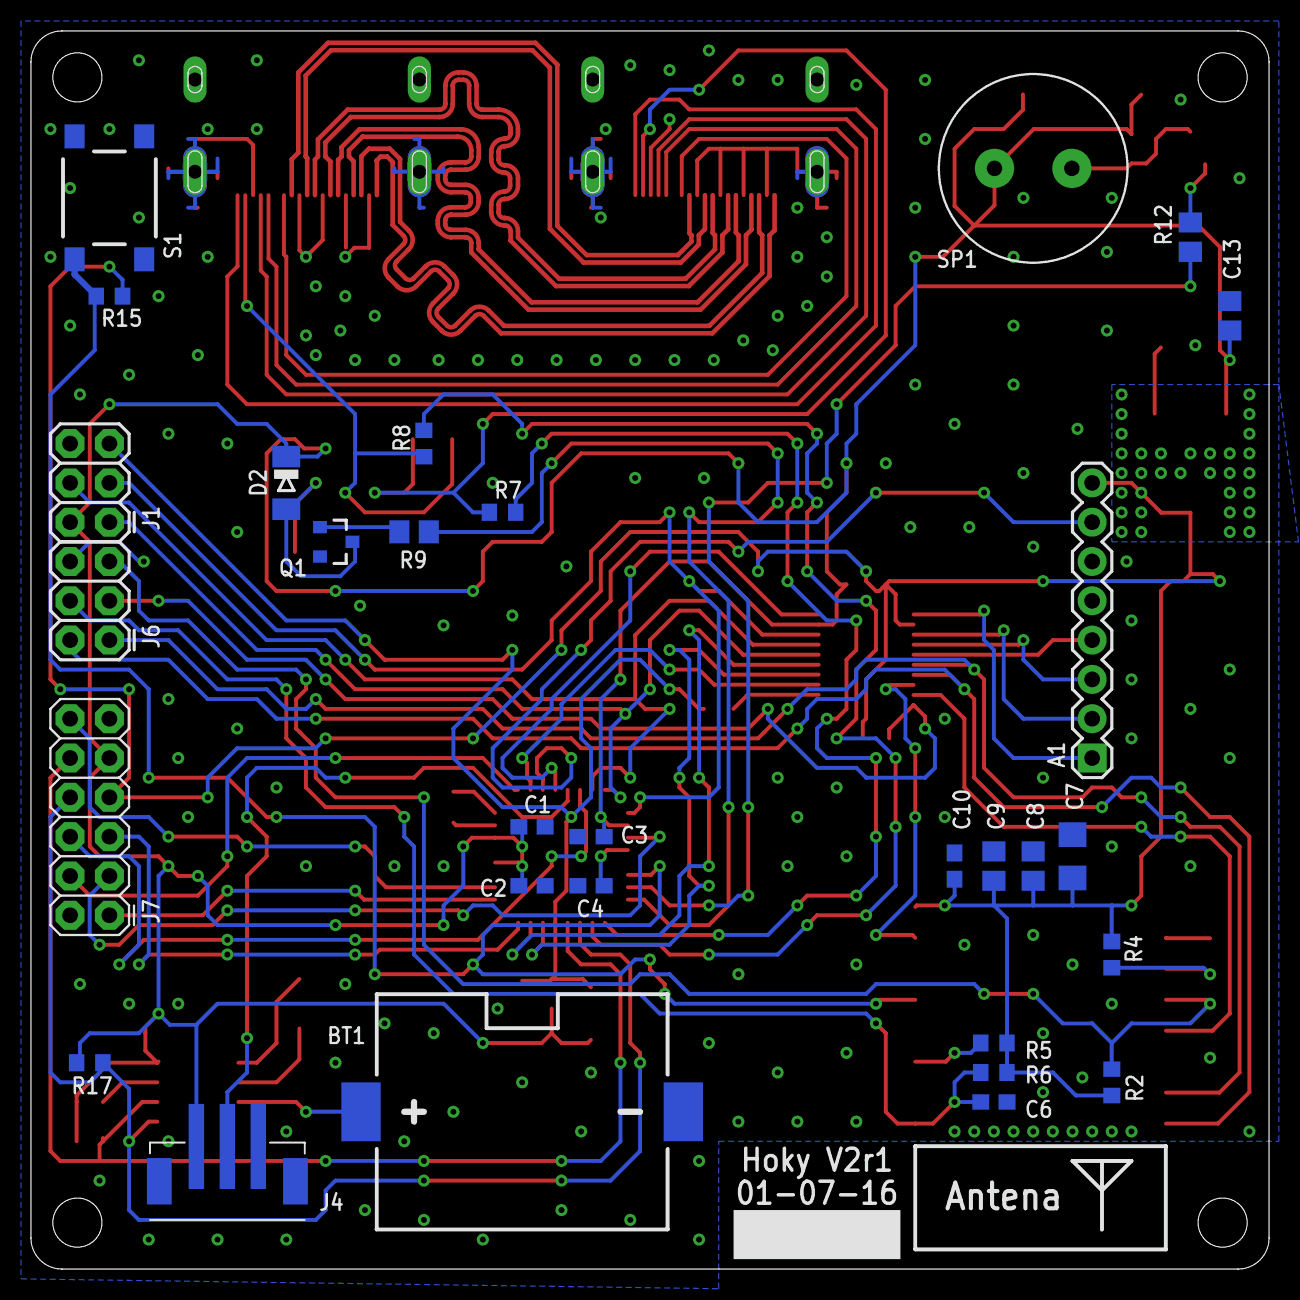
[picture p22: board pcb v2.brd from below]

Board: 2 copper layers, 80.0 x 80.0 mm, 58 parts (30 on the bottom side), 66 nets.

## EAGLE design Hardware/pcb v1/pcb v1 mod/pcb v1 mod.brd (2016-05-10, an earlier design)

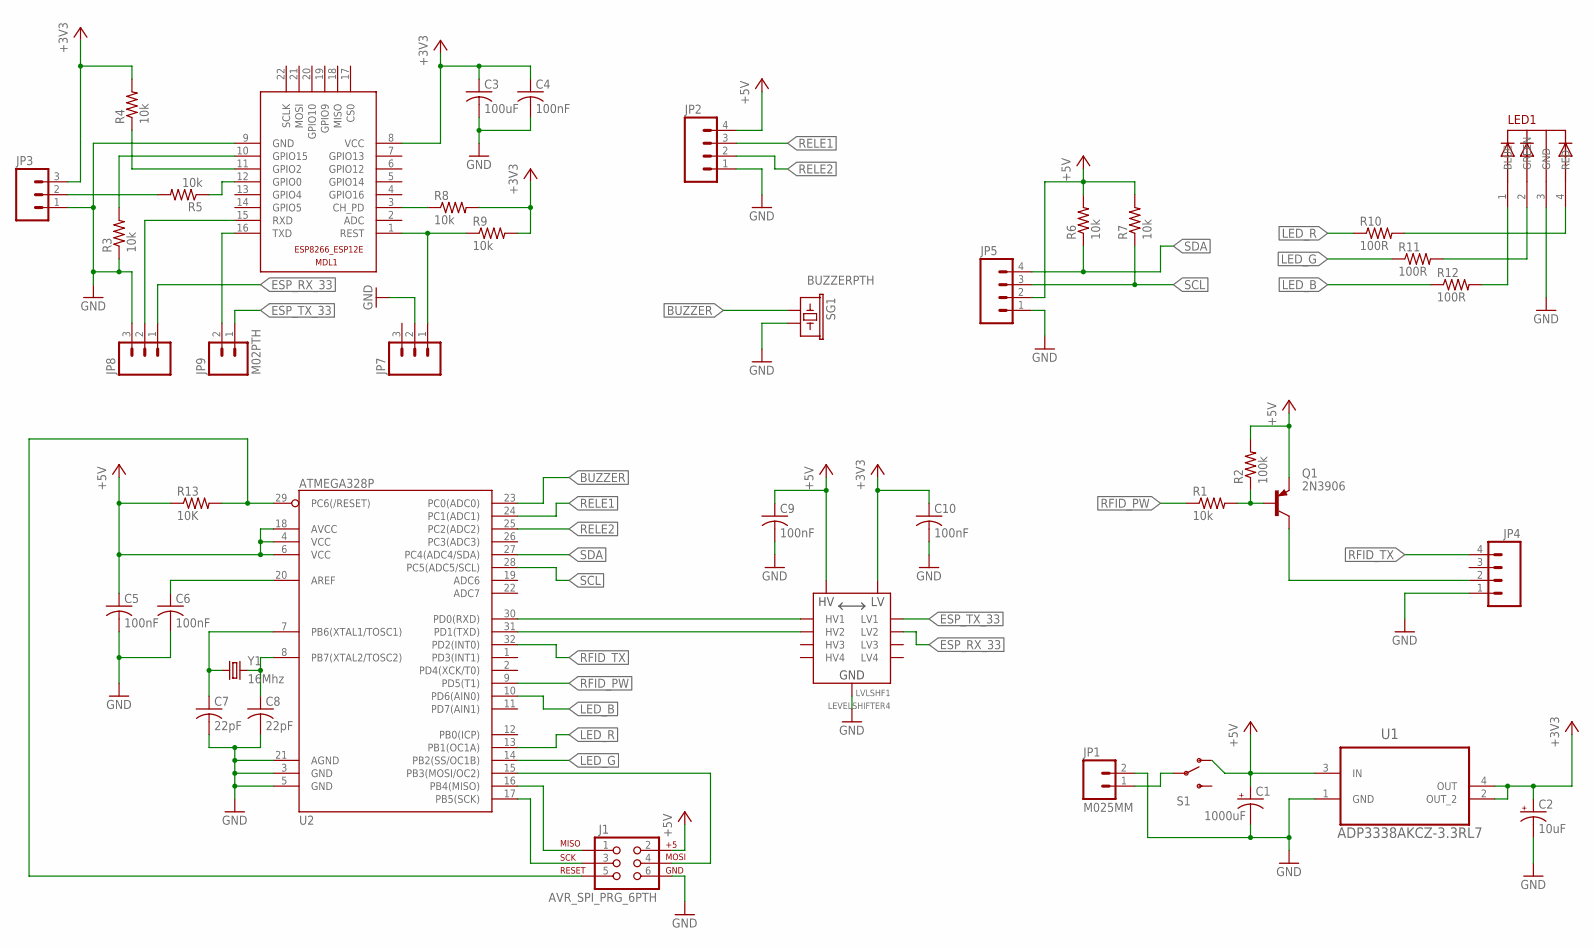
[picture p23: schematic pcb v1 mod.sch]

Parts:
C1: 1000uF; E2,5-6
C2: 10uF; E2,5-6
C3: 100uF; C1206
C4, C5, C6, C9, C10: 100nF; C0805
C7, C8: 22pF; C1206
J1: AVR_SPI_PRG_6PTH; 2X3
JP1: M025MM; SCREWTERMINAL-5MM-2
JP2, JP4, JP5: M041X04_NO_SILK; 1X04_NO_SILK
JP3, JP7, JP8: M03PTH; 1X03
JP9: M02PTH; 1X02
LED1: 5MMRGBLED; LED5MMRGB
LVLSHF1: LEVELSHIFTER4
MDL1: ESP8266-12EESP8266-ESP12E; ESP8266-ESP12E
Q1: 2N3906; TO92
R1, R3, R4, R5, R6, R7, R8, R9: 10k; R0805
R2: 100k; R0805
R10: 100R; R1206
R11, R12: 100R; R0805
R13: 10K; R0805
S1: SWITCH-SPDTPTH; SWITCH-SPDT
SG1: BUZZERPTH; BUZZER-12MM
U1: ADP3338AKCZ-3.3RL7; SOT230P700X180-4N
U2: ATMEGA328P; TQFP32-08
Y1: 16Mhz; HC49US

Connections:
+3V3: C2.+, C3.1, C4.1, C10.1, JP3.3, LVLSHF1.LV, MDL1.8 (VCC), R4.2, R8.2, R9.2, U1.2 (OUT_2), U1.4 (OUT)
+5V: C1.+, C5.1, C9.1, J1.2, JP2.4, JP5.2, LVLSHF1.HV, Q1.3 (E), R2.2, R6.2, R7.2, R13.1, S1.1 (O), U1.3 (IN), U2.4 (VCC), U2.6 (VCC), U2.18 (AVCC)
AT_RST: J1.5, R13.2, U2.29 (PC6(/RESET))
BUZZER: SG1.+ (1), U2.23 (PC0(ADC0))
ESP_RX_33: JP8.1, LVLSHF1.LV2
ESP_TX_33: JP9.1, LVLSHF1.LV1
GND: C1.-, C2.-, C3.2, C4.2, C5.2, C6.2, C7.2, C8.2, C9.2, C10.2, J1.6, JP1.2, JP2.1, JP3.1, JP4.1, JP5.1, JP7.2, JP8.3, LED1.3 (GND), LVLSHF1.GND, LVLSHF1.GND1 (GND), MDL1.9 (GND), R3.1, SG1.- (2), U1.1 (GND), U2.3 (GND), U2.5 (GND), U2.21 (AGND)
LED_B: R12.1, U2.10 (PD6(AIN0))
LED_G: R11.1, U2.14 (PB2(SS/OC1B))
LED_R: R10.1, U2.13 (PB1(OC1A))
unnamed: JP1.1, S1.2
unnamed: MDL1.3 (CH_PD), R8.1
unnamed: MDL1.11 (GPIO2), R4.1
unnamed: MDL1.12 (GPIO0), R5.1
unnamed: MDL1.10 (GPIO15), R3.2
unnamed: JP8.2, MDL1.15 (RXD)
unnamed: Q1.2 (B), R1.2, R2.1
unnamed: JP9.2, MDL1.16 (TXD)
unnamed: JP7.1, MDL1.1 (REST), R9.1
unnamed: LED1.4 (RED), R10.2
unnamed: C7.1, U2.7 (PB6(XTAL1/TOSC1)), Y1.1
unnamed: C8.1, U2.8 (PB7(XTAL2/TOSC2)), Y1.2
unnamed: C6.1, U2.20 (AREF)
unnamed: LED1.2 (GREEN), R11.2
unnamed: LED1.1 (BLUE), R12.2
unnamed: J1.3, U2.17 (PB5(SCK))
unnamed: J1.1, U2.16 (PB4(MISO))
unnamed: J1.4, U2.15 (PB3(MOSI/OC2))
unnamed: JP3.2, R5.2
unnamed: LVLSHF1.HV1, U2.30 (PD0(RXD))
unnamed: LVLSHF1.HV2, U2.31 (PD1(TXD))
unnamed: JP4.2, Q1.1 (C)
RELE1: JP2.3, U2.24 (PC1(ADC1))
RELE2: JP2.2, U2.25 (PC2(ADC2))
RFID_PW: R1.1, U2.9 (PD5(T1))
RFID_TX: JP4.4, U2.32 (PD2(INT0))
SCL: JP5.3, R7.1, U2.28 (PC5(ADC5/SCL))
SDA: JP5.4, R6.1, U2.27 (PC4(ADC4/SDA))

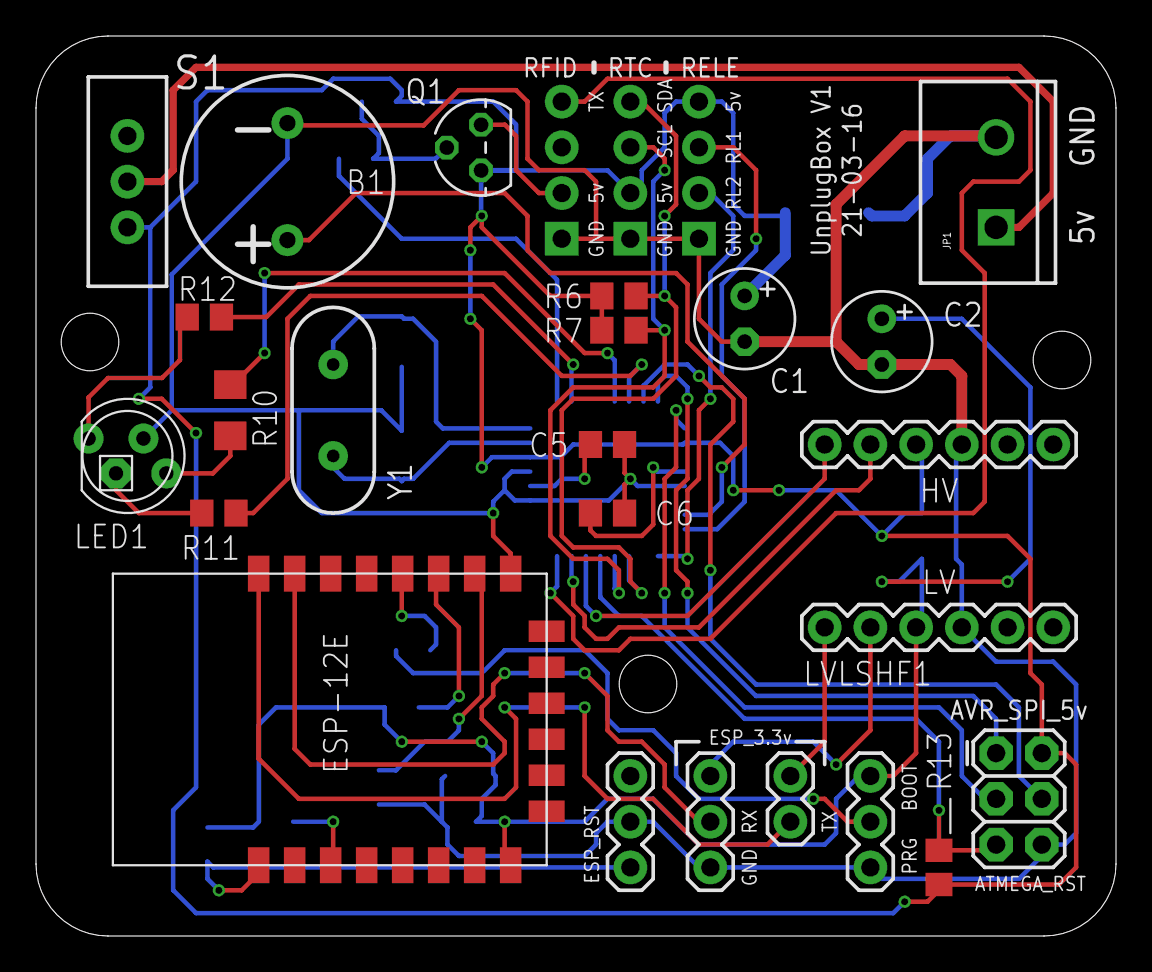
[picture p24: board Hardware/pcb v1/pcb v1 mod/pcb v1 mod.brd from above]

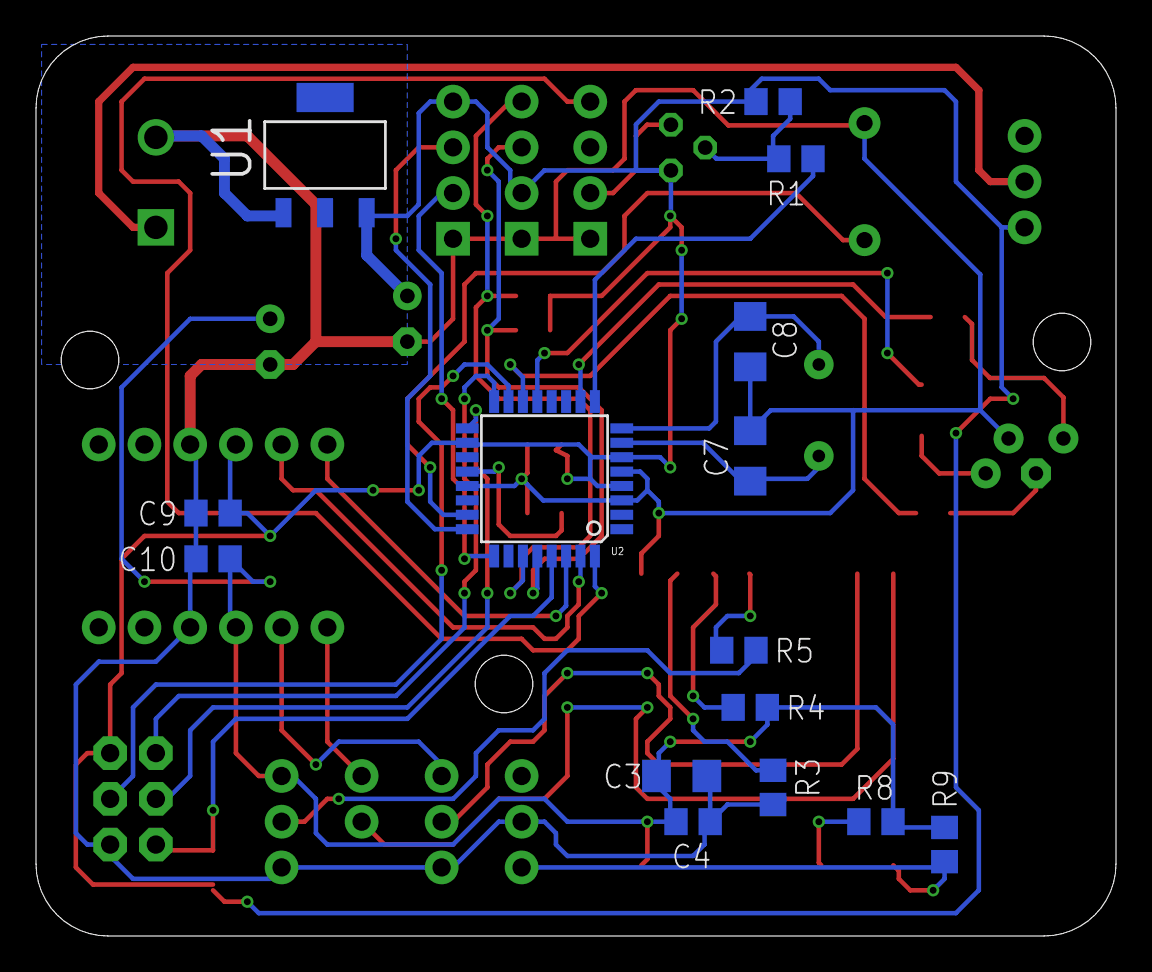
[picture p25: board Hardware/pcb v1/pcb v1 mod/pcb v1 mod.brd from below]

Board: 2 copper layers, 60.0 x 50.0 mm, 41 parts (15 on the bottom side), 38 nets.

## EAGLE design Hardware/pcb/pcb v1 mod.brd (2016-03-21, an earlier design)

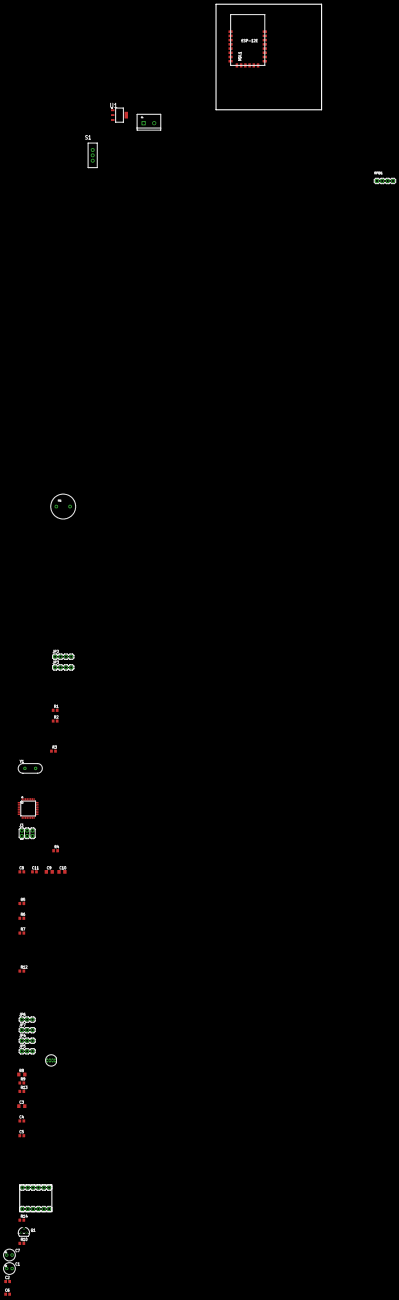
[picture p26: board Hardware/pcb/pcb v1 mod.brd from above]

Board: 2 copper layers, 143.0 x 572.0 mm, 42 parts (0 on the bottom side), 38 nets, no tracks yet.

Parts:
C1, C7: 10uF; E2,5-6
C2, C4, C5, C6, C8, C11: 100nF; C0805
C3: 1uF; C1206
C9, C10: 22pF; C1206
D1: LED-RGB-CC-THRUCLEAR; LED-RGB-THRU
J3: AVR_SPI_PRG_6PTH; 2X3
JP1: M025MM; SCREWTERMINAL-5MM-2
JP2, JP3: 1X04
JP4, JP5, JP6, JP7: 1X03
LVLSHF2: LEVELSHIFTER4
MDL1: ESP8266-ESP12E
Q1: 2N3906; TO92
R1, R2, R3, R5, R6, R7, R10, R12, R14: 10k; R0805
R4: 100K; R0805
R8: 160R; R1206
R9, R13: 100R; R0805
RFID1: GROVE-RFID
S1: SWITCH-SPDT
SG1: BUZZERPTH; BUZZER-12MM
U1: ADP3338AKCZ-3.3RL7; SOT230P700X180-4N
U3: ATMEGA328P; TQFP32-08
Y1: 16Mhz; HC49US

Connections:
+3V3: C1.+, C2.1, C3.1, C4.1, JP6.3, LVLSHF2.LV, MDL1.8, R3.2, R5.2, R7.2, U1.2, U1.4
+5V: C5.1, C6.1, C7.+, C8.1, J3.2, JP2.2, JP3.4, LVLSHF2.HV, Q1.3, R1.2, R2.2, R4.1, R14.2, S1.1, U1.3, U3.4, U3.6, U3.18
BUZZER: SG1.+, U3.23
ESP_RX_33: JP5.1, JP5.3, LVLSHF2.LV2
ESP_TX_33: JP4.1, JP4.3, LVLSHF2.LV1
GND: C1.-, C2.2, C3.2, C4.2, C5.2, C6.2, C7.-, C8.2, C9.2, C10.2, C11.2, D1.2, J3.6, JP1.1, JP2.1, JP3.1, JP6.1, JP7.2, LVLSHF2.GND, LVLSHF2.GND1, MDL1.9, R6.1, RFID1.4, SG1.-, U1.1, U3.3, U3.5, U3.21
LED_B: R13.1, U3.10
LED_G: R9.1, U3.14
LED_R: R8.1, U3.13
unnamed: JP1.2, S1.2
unnamed: MDL1.3, R5.1
unnamed: MDL1.11, R7.1
unnamed: MDL1.12, R12.1
unnamed: MDL1.10, R6.2
unnamed: JP5.2, MDL1.15
unnamed: Q1.2, R10.2, R14.1
unnamed: JP4.2, MDL1.16
unnamed: JP7.1, MDL1.1, R3.1
unnamed: D1.1, R8.2
unnamed: C9.1, U3.7, Y1.1
unnamed: C10.1, U3.8, Y1.2
unnamed: C11.1, U3.20
unnamed: D1.3, R9.2
unnamed: D1.4, R13.2
unnamed: J3.3, U3.17
unnamed: J3.1, U3.16
unnamed: J3.4, U3.15
unnamed: JP6.2, R12.2
unnamed: LVLSHF2.HV1, U3.30
unnamed: LVLSHF2.HV2, U3.31
unnamed: Q1.1, RFID1.3
unnamed: J3.5, R4.2, U3.29
RELE1: JP3.3, U3.24
RELE2: JP3.2, U3.25
RFID_PW: R10.1, U3.9
RFID_TX: RFID1.1, U3.32
SCL: JP2.3, R1.1, U3.28
SDA: JP2.4, R2.1, U3.27

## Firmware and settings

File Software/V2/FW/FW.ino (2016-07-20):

#include "RTClib.h"
#include <SoftwareSerial.h>

#define RFID_SS_3V3 8
#define RFID_OC_NRST 7
#define BUZZER A0
#define RELE A1
#define BOTON A7

SoftwareSerial debugSerial(3, 4);

void setup() {
	debugSerial.begin(115200);
}
enum Estado {bloqueado, desbloqueado, user, master};
Estado estado = bloqueado;

class Usuario {
public:
	Usuario() {
		id = 66;
	}
	byte id;
	byte master;
	byte nuidPICC[4];
	DateTime horario_inicio;
	DateTime horario_fin;
};

boolean intervalo_t(DateTime t, DateTime ti, DateTime tf) {
	return (t.hh > ti.hh || t.mm > ti.mm || t.ss > ti.ss)
	       && (t.hh < tf.hh || t.mm < tf.mm || t.ss < tf.ss);
}
boolean check_nuid(byte * nuid1, byte * nuid2) {
	return nuid1[0] != nuid2[0]
	       || nuid1[1] != nuid2[1]
	       || nuid1[2] != nuid2[2]
	       || nuid1[3] != nuid2[3];
}
boolean leer_tarjeta() {
	if(rfid.PICC_IsNewCardPresent()) {
		if(rfid.PICC_ReadCardSerial()) {
			return 1;
		}
	}
	return 0;
}

byte nusers=4;
Usuario users[4];
DateTime tiempo;

void loop() {
    //Lecturas de tarjetas, tiempo del RTC, etc...
	tarjeta = leer_tarjeta();
    //Transiciones de estados, no leer nada aqui, usar solo variables fijas.
	if(estado == bloqueado) {
        //Para cada usuario...
		for(int i = 0; i < nusers; i++) {
            //Ignorar usuarios no creados.
			if(users[i].id != 0) {
                //Transicion a horario permitido
				if(intervalo_t(tiempo, users[i].horario_inicio, users[i].horario_fin)) {
					estado = desbloqueado;
				}
                //Si hay tarjeta puesta...
				if(tarjeta) {
                    //Revisar de quien es la tarjeta
					if(check_nuid(rfid.uid.uidByte, users[i].nuidPICC)) {
                        //Transicion a modo master o revisar el tiempo restante del ninho
						if(users[i].master) {
							estado = master;
						} else {
                            //Revisar el tiempo restante
						}
					}
				}
			}
		}
	} else if(estado == desbloqueado) {
	} else if(estado == user) {
	} else if(estado == master) {
	}
}

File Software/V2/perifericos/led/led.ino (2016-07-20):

/*
 * light_ws2812 example
 *
 * Created: 07.03.2014 12:49:30
 *  Author: Matthias Riegler
 */

#include "WS2812.h"

WS2812 LED(7); // 1 LED

cRGB value;

byte anim[12] = {0b01001001,
	             0b01001000,
	             0b00100101,
                 0b00100100,
	             0b01001001,
                 0b01001000,
	             0b00100101,
                 0b00100100,
	             0b01001001,
                 0b01001000,
	             0b00100101,
                 0b00100100};

void setup() {
	Serial.begin(115200);
	LED.setOutput(9);     // Digital Pin 9
	value.b = 0;
	value.g = 0;
	value.r = 0;
	for(int i = 0; i < 7; i++) {
		LED.set_crgb_at(i, value);
	}
	LED.sync();
}
int n = 12;
unsigned long dt = 1000;
unsigned long t = 0;
unsigned long pt = 0;
unsigned long offset = 0;
int kk=0;
//Fin de millis -> t = 0 + el resto de la division del maximo millis con dt ¿?¿?¿?¿?¿?¿?¿?¿?
void loop() {
	t = millis();
	int tf = t % dt;
	int nf = ((t / dt) % n);
	byte pframe = anim[nf == 0 ? n - 1 : nf - 1];
	byte frame = anim[nf];
	for(int i = 0; i < 7; i++) {
		boolean pbit = bitRead(pframe, i);
		boolean bit = bitRead(frame, i);
		double ti = constrain(3*double(tf) / double(dt),0.0,1.0);
		byte pix = byte((pbit * 255.0 * (1 - ti)) + (bit * 255.0 * ti));
		value.SetHSV(i == 0 ? 0 : 30, 255, i == 0 ? pix : map(pix,0,255,0,200));
		LED.set_crgb_at(i, value);
	}
	LED.sync();
    pt=t;
}

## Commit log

2016-03-16 PCB version 1
    [pcb v1.brd, pcb v1.sch]
2016-03-16 Añadir partes y gitignore
    [pcb v1.brd, pcb v1.sch]
2016-03-17 Perifericos agregados
    Modulo Grove RFID
    RTC
    2 Reles
    Regulador 3.3v
    Buzzer
    LED RGB
    [pcb v1.brd, pcb v1.sch]
2016-03-17 Versión modular
    [pcb v1 mod.brd, pcb v1 mod.sch]
2016-03-17 Quitar el rtc
    [pcb v1 mod.brd, pcb v1 mod.sch]
2016-03-18 Modulo reles
    [pcb v1 mod.brd, pcb v1 mod.sch]
2016-03-20 esp y atmega328
    [pcb v1 mod.brd, pcb v1 mod.sch]
2016-03-21 Esquematico completo
    [pcb v1 mod.brd, pcb v1 mod.sch]
2016-03-21 Ruteo completo
    [pcb v1 mod.GBL, pcb v1 mod.GBO, pcb v1 mod.GBP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]
2016-03-21 Correcciones placa
    [pcb v1 mod.GBL, pcb v1 mod.GBO, pcb v1 mod.GBP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]
2016-03-22 Cambios menores
    [pcb v1 mod.brd, pcb v1 mod.sch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]
2016-03-22 BOM excel
    Falta agregar link proveedores
    [BOM.xlsx]
2016-03-22 Arreglo alineacion gerber
    [pcb v1 mod.GBL, pcb v1 mod.GBO, pcb v1 mod.GBP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]
2016-03-29 Agregada la sección Software, con algunos módulos de prueba en Firmware.
2016-03-29 agregada información sobre el IDE en el readme.txt
2016-03-30 Ordene todo el contenido de la carpeta Software y agregue la libreria Metro como local en box_atmega_v00. Este ultimo ahora es compilable
2016-04-01 Se cambiaron pines y se inviertieron el sentido del rele y del transistor al rfid.
2016-04-02 Version preparada para Arduino Day. Se incluyo LED RGB y sonido. Tiempo por defecto 5 minutos.
2016-04-08 Cambio de valores de condensadores
    [pcb v1 mod.brd, pcb v1 mod.sch]
2016-04-10 dibujos de las dimensiones de las placas
    [pcb v1 mod.dxf, reles.dxf, rfid y rtc.dxf]
2016-04-12 Cambios en algunas resistencias
    [pcb v1 mod.brd, pcb v1 mod.sch]
2016-04-14 cambio resistencia led
    [pcb v1 mod.brd, pcb v1 mod.sch]
2016-04-18 La v01 del atmega tiene los pines actuales de la placa de Diego.
2016-04-18 Se agrego el pin A2 al sw serial del RFID para debuggear.
2016-04-19 códigos de prueba
    [pcb v1 mod.csv]
2016-04-21 Cambio valor C3
    [pcb v1 mod.brd, pcb v1 mod.sch]
2016-05-10 pcb v2 atmega y rtc
    [BOM.xlsx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]
2016-05-10 pcb v2 buzzer
    [pcb v2.brd, pcb v2.sch]
2016-05-11 pcb v2 rfid
    [pcb v2.brd, pcb v2.sch]
2016-05-12 libreria AD8192
    [pcb v2.brd, pcb v2.sch]
2016-05-12 libreria TXS0108E
    [pcb v2.brd, pcb v2.sch]
2016-05-13 avances pcb v2
    [hdmi.dxf, pcb v2.brd, pcb v2.sch]
2016-05-13 v2 esquematico semiterminado
    [pcb v2.brd, pcb v2.sch]
2016-05-17 v2 esquematico completo
    [pcb v2.brd, pcb v2.sch]
2016-05-17 Comienzo ruteo
    [pcb v2.brd, pcb v2.sch]
2016-05-20 posiciones componentes externos
    [pcb v2.brd, pcb v2.sch]
2016-05-20 ruteo tdms
    [pcb v2.brd, pcb v2.sch]
2016-05-20 ruteo hdmi completo
    [pcb v2.brd, pcb v2.sch]
2016-05-22 avance ruteo
    [pcb v2.brd, pcb v2.sch]
2016-05-23 ruteo completo
    falta arreglar la serigrafia
    [pcb v2.brd, pcb v2.sch]
2016-05-23 gerbers y render
    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
    [pcb v2.GBL, pcb v2.GBO, pcb v2.GBP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]
2016-05-23 Serigrafia arreglada
    [pcb v2.brd, pcb v2.sch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]
2016-05-24 documentación para diseño
    [pcb v2.brd, pcb v2.sch]
2016-05-26 bom y cambios menores en la pcb
    [hdmi.dxf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]
2016-05-26 bom actualizado y con códigos
    [BOM.xlsx, pcb v2.csv]
2016-05-30 cambio de boton
    [pcb v2.brd, pcb v2.sch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]
2016-05-30 arreglo serigrafia
    [pcb v2.brd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]
2016-06-01 Orden e Inicio por parte de SS Firmware
    [Arduino-Uno-r3-with-RFID-RC522.fzz]
2016-06-01 Boton conectado al esp
    [pcb v2.brd, pcb v2.sch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]
2016-06-01 bordes redondeados
    [pcb v2.GBL, pcb v2.GBO, pcb v2.GBP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]
2016-06-02 arreglo dimension
    [pcb v2.GBL, pcb v2.GBO, pcb v2.GBP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]
2016-06-02 arreglo gerber itead
2016-06-09 gerber osh park
    [pcb v2.GBL, pcb v2.GBO, pcb v2.GBP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]
2016-07-01 revertir los cambios de osh park
    [pcb v2.brd, pcb v2.sch]
2016-07-02 pcb V2r1
    Gerbers de itead y seeedstudio actualizados
    [pcb v2.brd, pcb v2.sch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]
2016-07-05 cambios bom
    [BOM.xlsx]
2016-07-05 arreglo hdmi v2r1
    [pcb v2.brd, pcb v2.sch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]
2016-07-12 Comienzo pcb V3
    [pcb v3.brd, pcb v3.sch]
2016-07-13 rtc y led V3
    [pcb v3.brd, pcb v3.sch]
2016-07-13 esquematico y bom v3 completo
    [bom.csv, bom.xlsx, pcb v3.brd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]
2016-07-20 Ruteo pcb V3 completo
    [bom.xlsx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]
2016-07-29 gerbers v3
    [pcb v3.brd, pcb v3.sch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]
2016-07-29 gerbers v3 itead
    [pcb v3.GBL, pcb v3.GBO, pcb v3.GBP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]
2016-08-04 bom v3 actualizado
    [bom.csv, bom.xlsx]

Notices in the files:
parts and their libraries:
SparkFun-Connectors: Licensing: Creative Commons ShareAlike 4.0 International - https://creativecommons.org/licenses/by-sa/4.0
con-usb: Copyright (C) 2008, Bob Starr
